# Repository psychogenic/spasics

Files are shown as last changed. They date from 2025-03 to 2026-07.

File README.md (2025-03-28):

# SpASICs
----------

Scratch repo for work, thoughts and notes about the spasics project: sending an ASIC to space!

It may be possible for [Tiny Tapeout](https://tinytapeout.com/) to include an experiment module aboard a [pocketQube](https://en.wikipedia.org/wiki/PocketQube) class satellite, so am collecting preliminary work on this here, in the hopes of getting ideas and feedback.

## Basic Requirements

Details on the objectives and requirements are all in the PRD, [SpASICs: ASIC Modular satellite experimentation board requirements](doc/SpASICsRequirements.md).  This is also available as [a PDF](doc/spasics.pdf).

## TODO

In addition to feedback on the PRD itself, the following require further work, feedback and ideas:

   * A means to safely run arbitrary, user-submitted, experiments.  Short version is we can't hang, we can't die, no matter what.  The proposed/sample implementation is [experiment_runner.py](python/experiment_runner.py) 
   
   * A complete API for commands and responses from the base system to our module.  Details on that are in [Experiment Module API](doc/ExperimentModuleAPI.md).
   
   * A means to safely update the system (ideally this would go all the way to the uPython firmware itself but, owing to bw constraints, this may be restricted to everything above that layer).  I would like to see something like a 2-slot OTA system, where we have everything in two places, run from slot A, update to slot B, attempt to run from slot B and revert to slot A on failure otherwise slot B becomes primary... that sort of thing.  TBD in [Firmware Updates](doc/FirmwareUpdates.md).
   
   * A byte-efficient means of patching the system.  Some updates may only be changes to a few lines of code, what is the most effective means of transmitting this data?  Also TBD in [Firmware Updates](doc/FirmwareUpdates.md).
   
   * Resilient data stores for outgoing data queues, log data, scheduling information etc 
   
   * Implementation code for above, once defined
   
   * More TODOs

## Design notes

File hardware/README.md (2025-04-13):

# Experiment Module Hardware

A single PCB created to host both the ASIC and the platform for the Experiment Run and Data Collection Framework (an RP2040) for inclusion within the [pocketQube](https://en.wikipedia.org/wiki/PocketQube) class satellite.

In addition to the meeting requirements related to being included in the launch (e.g. a 3mm height maximum, no silk screen, etc), a primary goals were to

  * provide a seamless path to running [SDK](https://github.com/TinyTapeout/tt-micropython-firmware) and existing ASIC project code with minimal disruption; and
  
  * reuse as much prior-tested components and circuitry
  
Thus, to the maximum extent possible, parts and pinouts were preserved, while major schematic elements were reproduced from the [demoboard](https://github.com/tinytapeout/tt-demo-pcb) and [ASIC breakout](https://github.com/tinyTapeout/breakout-pcb).

## Board 

[Explore the design online using KiCanvas](https://kicanvas.org/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)

The basic schematic is

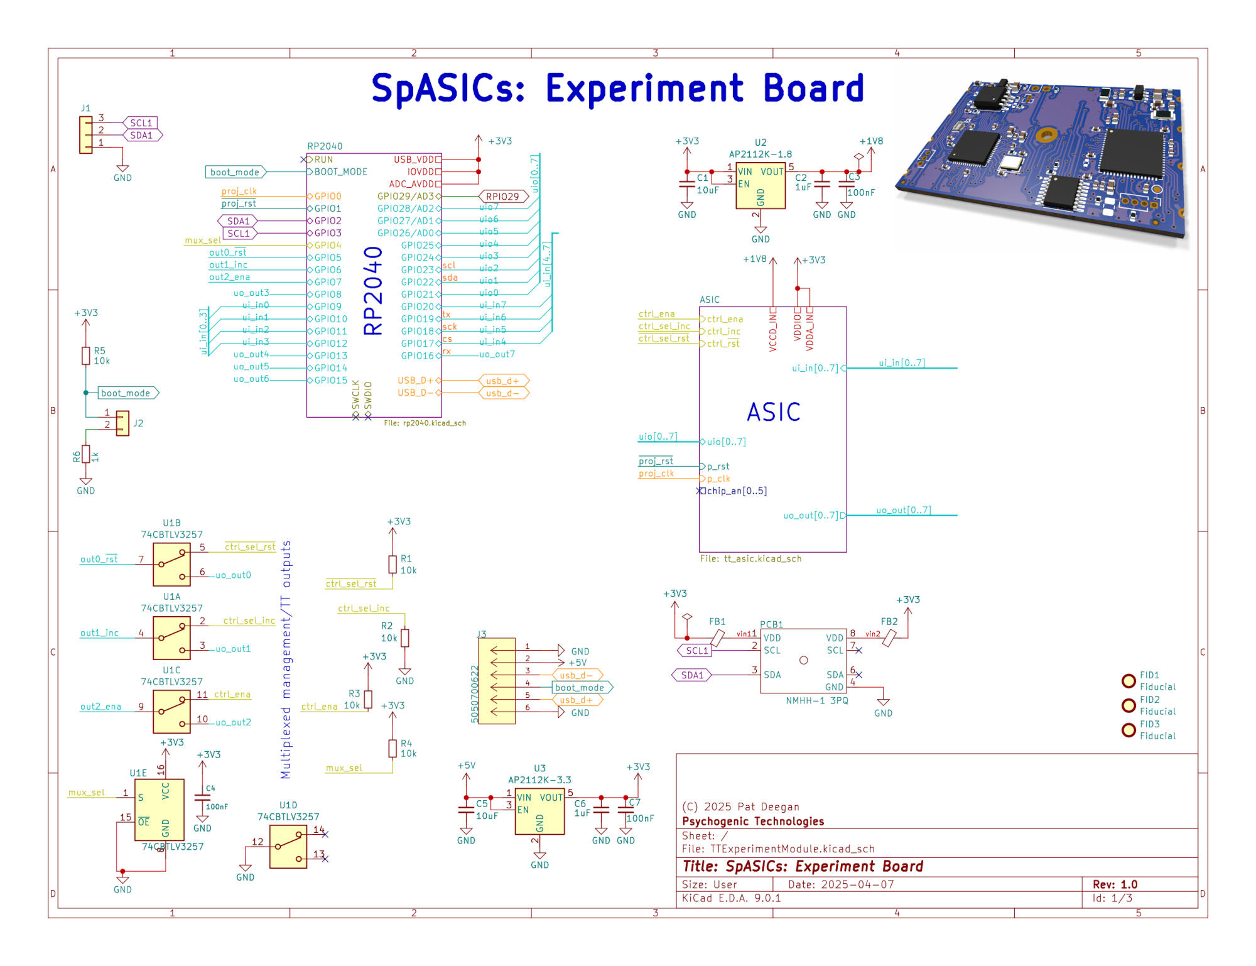
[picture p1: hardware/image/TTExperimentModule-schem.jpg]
TT Exp Board Schematic


and you can consult the entire schematic in [the PDF](image/TTExperimentModule.pdf).

The PCB is 45x30mm and is mainly concerned with routing I/O around the big hole in the middle of the board.

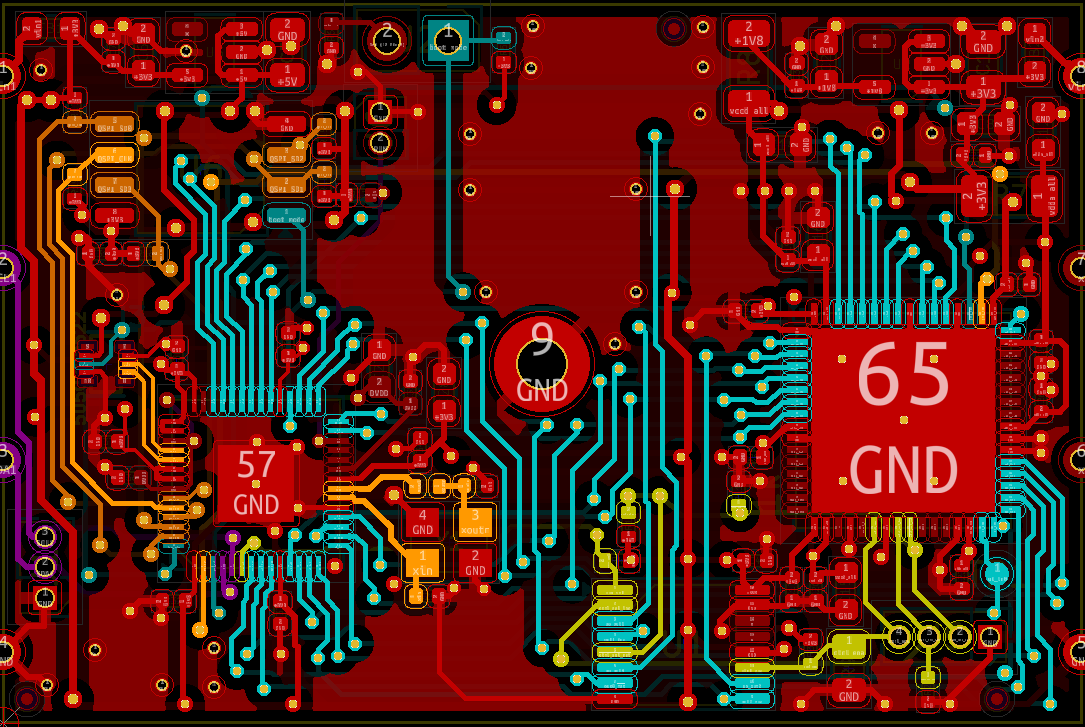
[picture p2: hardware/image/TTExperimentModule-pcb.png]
TT Exp Board PCB


## Sources

The entire [KiCad](https://www.kicad.org/) project is in [TTExperimentModule](./TTExperimentModule)

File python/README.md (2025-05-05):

# SpASICs Python Driver

This micropython codebase allows:

  * responding to the satellite as an I2C slave device
  
  * running ASIC design experiments and getting results back as they proceed and once they are done

It implements an API that supports:

  * launching and aborting user experiments
  
  * fetching status information
  
  * ping and reboot

There is also a framework in place to allow easy development of experiments to run on the module.  If you're interested in that, see the next section and you can ignore the rest.
  
## Experiment Development

Write some code that will be run IN SPACE!  Can be on your own design on TT06, or someone else's.

I've now created a framework to allow you to develop and test your spASIC experiments on TT demoboards.  It's an easy way to see that it's working and doing what you hope, in a way that integrates seamlessly with the spASIC-specific system on the experiment board.

The full description is on [spasic_experiment_testing](https://github.com/psychogenic/spasic_experiment_testing), short version is to

   1. Fork that [spasic_experiment_testing repository](https://github.com/psychogenic/spasic_experiment_testing)

   2. In your clone, create a package under `spasic.experiment` using `spasic.experiment.tt_um_test` as a guide

   3. Copy all the modules over to the demoboard and run your tests using the ExperimentRunner to ensure all is well

   4. Make a pull-request to merge your experiment prior to launch

## Testing

If you want to test this entire codebase, you'll need two devices:

  * one to play the role of the spasics board; and
  
  * one to play the role of the satellite and bus master.
  
to wire them up with 3 shared lines--I2C SDA, SCL and a common ground--and to get a little deeper into the weeds to have the "spasics board" setup.

### satellite simulator

For the satellite, there is [simulator code](./i2c_client_test.py) that can be installed on any micropython device, such as a Pi Pico, as `main.py` and allows you to use the REPL to talk over I2C to the spasics board. 

This code knows how to craft messages and interpret what comes back and has useful methods, e.g.

  * `sim.run_experiment_now(EXPID)` to launch an experiment
  
  * `sim.abort()` to stop an experiment in progress 
  
  * `sim.status()` to read status (experiment running, current results value, etc)
  
  * `sim.ping()` simple check that spasics is alive 
  
  * `sim.reboot()` ... you can probably guess, and
  
  * `sim.read_pending()` to fetch any pending messages on the spasics, such as results of experiments that have completed.
 
### spasics board

Getting a spasics board running is a bit more involved, as the RP2 micropython does *not* currently support I2C slave implementations.

So I had to go deep into the weeds and code up a micropython C module to get it working with our Python.

You'll therefore need a version of uPython with this module built-in.  I have the uPython branch with the C module here: [https://github.com/psychogenic/micropython/tree/rp2-i2cslave](https://github.com/psychogenic/micropython/tree/rp2-i2cslave)

Get that, checkout the rp2-i2cslave branch (`git checkout rp2-i2cslave`), and then copy:

   * all the contents of the [ttboard module directory](https://github.com/TinyTapeout/tt-micropython-firmware/tree/main/src)
   
   * all the contents of the [microcotb module directory](https://github.com/psychogenic/microcotb/tree/main/src)
   
Into `ports/rp2/modules`.  Then build, which is mostly just go into `ports/rp2` and

```
make submodules
make
```

Then you'll have a `firmware.uf2` in build-somethingsomething that you can install.

If you install this UF2, you'll have the spasics basics and you could simply copy over the [spasics API modules](https://github.com/psychogenic/spasics/tree/main/python/spasic) and the [shuttles](https://github.com/psychogenic/spasics/tree/main/python/shuttles) directory and [config.ini](https://github.com/psychogenic/spasics/blob/main/python/config.ini) [i2c_server.py](https://github.com/psychogenic/spasics/blob/main/python/i2c_server.py) and [main.py](https://github.com/psychogenic/spasics/blob/main/python/main.py), from here, into the root of the micropython filesystem.

However, if you are playing deep enough that you have to install the UF2 repeatedly, this process of copying everything over can quickly get tiresome.  

If you want, you can instead take that base UF2 and automatically have the filesystem filled with all the goodness.  To do this, create a directory that will act as the root of the FS, say `upyfs`.  Then, into that directory copy over all the above, so you have:

```
	upyfs/config.ini
	upyfs/i2c_server.py
	upyfs/main.py
	upyfs/shuttles/
	upyfs/spasic/
```

Now, install [uf2utils](https://pypi.org/project/uf2utils/) using `pip install uf2utils`.  With the `firmware.uf2` and the root directory in hand, you can now run

```
python -m uf2utils.examples.custom_pico \
   --fs_root upyfs/ --upython firmware.uf2 \
   --out /tmp/mybundled-distro.uf2
```

Installing the new `/tmp/mybundled-distro.uf2` rather than just the bare `firmware.uf2` will be a bit slower, but it will include everything that was under your `upyfs`.  Horray.
￼

For the spasics board, SDA is GPIO2 and SCL is GPIO3, by default. On TT06 demoboards, GPIO2 is the mux control reset (cRST on the header at the top) and GPIO3 is mux control increment (cINC on same header).  So, if you run this on a demoboard, you'll either want to remove the ASIC or remap the I2C pins to something better (say some bidirs, say uio1 and uio2 bidirs... main thing is that they use I2C1 on the RP2 unless you want to mess in the C module).

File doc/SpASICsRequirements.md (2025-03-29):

# SpASICs: ASIC Modular satellite experimentation board requirements      
--------------------------------------------------------------------

[Pat Deegan](https://psychogenic.com)

2025-03-26

### 1 Introduction

It may be possible for [Tiny Tapeout](https://tinytapeout.com/) to include an experiment module aboard a [pocketQube](https://en.wikipedia.org/wiki/PocketQube) class satellite and we would like to take advantage of this opportunity to put one of the ASICs produced into low earth orbit in order to run user and interact with user designs, to collect and report data from these runs back to Earth.

To attain this goal, three fundamental elements must be designed to work together:

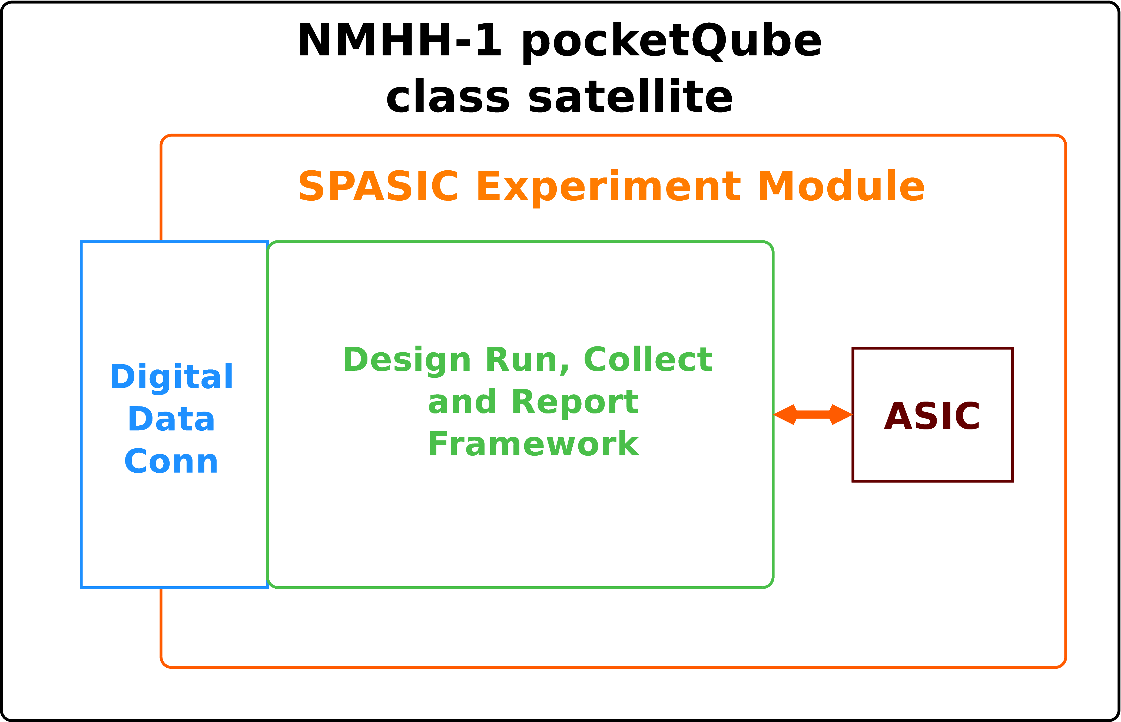
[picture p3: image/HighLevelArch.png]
High Level Architecture


1.  The experiment module: a physical PCB hosting ASIC and supporting components
    
2.  A software framework to schedule and perform runs of experiments, which will enable designs, interact with them, collect data and prepare it for reporting results; and
    
3.  The digital data connection: the means for the experiment module to communicate with and be controlled by the host satellite.

### 2 Objectives

The core objective is to get user designs operating in low earth orbit and, in doing so, acquire experience with and design tools for performing experiments in this constrained and unique environment.

The chips host a variety of designs submitted by creators and Tiny Tapeout is an educational project centred on education and community, so a collaborative model where designers can submit tests for particular projects is highly desirable. However,

because in these circumstances physical access is impossible and communications are extremely limited in both the amount of data that may be exchanged and the windows during which such exchanges are possible, the aim is to design a system that allows these user contributions while being resilient, fault-tolerant and simple.

#### 2.1 Experiment Module

The experiment module hardware is the physical PCB that may be hosted by the NMHH-1 pocketQube satellite. It’s objectives are to:

1.  Host a Tiny Tapeout ASIC and the minimal set of required supporting components for it to operate
    
2.  Meet the NMHH-1 requirements for 3PQ size pocketQube class satellite experiment modules and be suitable for inclusion in the launch
    
3.  Allow for communication between the satellite framework and the experiment run and data collection system

#### 2.2 Experiment Run and Data Collection Framework

##### 2.2.1 Experimental Run

An experimental run is the combination of:

1.  the specific design to enable on the ASIC
    
2.  any interaction required with the project, including clocking, values input through I/O and timing thereof
    
3.  data collection, including monitoring project outputs
    
4.  data processing, which condenses collected data into some form of result to be logged or returned back to base station
    
5.  reporting, i.e. providing information on the experimental run in an agreed-upon form

##### 2.2.2 Core Function

The base function of this framework is to run experiments on behalf of users. It will

1.  Maintain the set of potential design experiments
    
2.  Maintain the schedule of experimental runs
    
3.  Allocate time and processing to experimental runs according to the schedule
    
4.  Maintain records of experimental runs performed
    
5.  Collect, prepare and queue data reported by experimental runs
    
6.  Provide experimental run data to the Digital Data Communications layer on request
    
7.  Keep track of which reports are pending or have already been transmitted
    
8.  Be capable of reporting information on it’s own state, including health, information about up-time, experiment queue, global success rate

The objective is for this system to run autonomously. For example, if we suddenly could no longer communicate up to the satellite, we would still be able to receive regular reports on the set of design experiments as it was configured on last update.

##### 2.2.3 Management Function

In addition to its core function of actually performing experimental runs, the framework must allow for management functions that let us

1.  Enable or disable specific experimental runs
    
2.  Change the scheduling or weight of particular design experiments
    
3.  Set system-level parameters and limits, including system clock frequency
    
4.  Update experimental run execution code
    
5.  Update the platform firmware itself

These last two points are objectives that would be ideal to support but are subject to the extreme bandwidth constraints and difficult to implement in a manner that is guaranteed to be fault-tolerant, with item 4 potentially putting the entire platform at risk... further consideration needed here.

#### 2.3 Digital Data Communications with pocketQube

The pocketQube digital data communications protocol is a simple, 3 command, 100kHz I2C that treats the experiment module as a slave device and has only 3 commands:

1.  read
    
2.  write
    
3.  time synch

From our side, the objectives are

1.  Support handling the defined I2C messages addressed to our module and to general-call broadcasts
    
2.  Synchronize system time to satellite on reception of time synch broadcasts
    
3.  Have a clearly defined API which can be transported as payload data within the established read/write protocol
    
4.  Support all the functions of the Experiment Run and Data Collection Framework within the constraints of the limited throughput of the digital data communications protocol

### 3 Requirements

#### 3.1 Experiment Module

The experiment module PCB requirements and constraints are detailed in the “NMHH-1 3PQ size pocketQube class satellite Experiment Module” document (nmhh1\_experiments\_eng.pdf) and that document should be referred to for all details. Our module must at a minimum include

1.  a Tiny Tapeout ASIC
    
2.  a means to manage and interact with that ASIC, nominally an RP2040 MCU
    
3.  interconnects between the MCU and the ASIC
    
4.  supporting components, such as flash memory

#### 3.2 Experiment Run and Data Collection Framework

The software framework must:

1.  Be remotely updatable, at a minimum in terms of all code above the base micropython environment and data stored on the filesystem
    
2.  Prioritize responsivity and always being in a state that will react to remote commands and updates
    
3.  Allow for loading experiments in a modular fashion, without being vulnerable to faulty code within (meaning being able to recover from exceptions, crashes or hangs in user-submitted code)
    
4.  Provide a standardized mechanism for defining user-defined test units and including them within the schedule
    
5.  Provide a standardized means of reporting experimental run results
    
6.  Be able to run autonomously while supporting functions to manage scheduling, data stores and behaviour
    
7.  Be “re-entrant” in the sense that it minimizes losses to state to at most the data for a single run in progress should power interrupted at any moment
    
8.  Have a means to check and handle priority commands or start-up or at any point, in order to abort or amend work in progress

#### 3.3 Digital Data Communications with pocketQube

The Digital Data Comms layer must:

1.  Respond correctly to module-addressed and broadcast messages over the I2C bus
    
2.  Have priority over the experiment run and data collection framework, in order to respond in a timely manner to the satellite and allow for management regardless of experimental run behaviour
    
3.  Provide a means to safely override the assigned module address

### 4 Design Constraints

#### 4.1 Experiment Module

Refer to “NMHH-1 3PQ size pocketQube class satellite Experiment Module” document (nmhh1\_experiments\_eng.pdf) for all details. Important constraints to keep in mind include

1.  The PCB must match the prescribed footprint and may have a maximum height of 3mm (including the board itself), be single-sided, gold plated, use 60/40 tin-lead eutectic and not include silk screen
    
2.  Total weight may not exceed 50g
    
3.  Power supply is 3v3 (2.7V - 3.5V)
    
4.  Power draw is limited to 100mA bursts, with an average consumption (over 90 minutes) of at most 34mA

#### 4.2 Experiment Run and Data Collection Framework

The data collection framework’s main constraints are related to memory, namely

1.  that it be able to load itself and modular experimental runs within the limits of available RAM
    
2.  that it be able to rely on the flash memory as a store for programs and collected results

#### 4.3 Digital Data Communications with pocketQube

Constraints related to communications are:

1.  Speed: the I2C bus operates at 100kHz
    
2.  Bandwidth: read and write commands have fixed payloads and we must encapsulate both data and meta-information (commands) within

##### 4.3.1 Write command

Each write, from satellite to our module, is 8 bytes of data. This severely limits the amount of information we can transfer to the module, making things like updating code rather difficult as they would be forced into a great deal of transactions on the bus. Ignoring the case of large updates, simple commands could be structured as

COMMAND DATA\[6:0\]

allowing for 7 bytes of relevant payload for any given command, with a maximum of 256 distinct commands. This can be further broken down using subcommand bytes, e.g.

SETEXPERIMENT PARAM VALUE\[5:0\]

so we could define

SETEXPERIMENT DESIGNID LOWBYTE HIGHBYTE

or

SETEXPERIMENT WEIGHT VALUE

etc.

##### 4.3.2 Read command

On each read, the experiment module is expected to send exactly 16 bytes of data. The satellite can store up to 7 such reads (a total of 112 bytes) for transmission to base station. This implies that reads must either

*   Always return a specific type of data
    
*   Sacrifice a portion of those limited returned bytes as metadata, indicating the how to interpret bytes or
    
*   Be setup in some manner by a previous write, e.g. to request specific data on next read

### 5 Assumptions and Dependencies

Core assumptions to be confirmed or amended.

1.  Module will be powered on at least 6 hours of every 24
    
2.  Under standard operating conditions, power delivery will be uninterrupted for periods of at least 20 minutes

3.  While powered, over any period of 60 seconds there will always be at least one I2C data communication transaction addressed to the module
    
4.  Ambient/materials in physical contact with the experiment module will always be between -40 and +80 degrees Celsius
    
5.  Assuming a ground plane connected via 4x 0.5mm thermal reliefs to the large plated through hole in the centre of the PCB, in combination of mechanical fastening and electrical connectivity of the experiment module is sufficient to draw and dissipate a steady 115mW of waste heat.
    
6.  The satellite can hold and write blocks of at least 50kB of data to the experiment module (split into an appropriate number of 8 byte payload write transactions)
    
7.  Writes of larger blocks of data, as described in the previous point, will occur sequentially and over a period of continuously powered operation
    
8.  We may queue both simple write commands, sending data to the experiment module, and write+read sequences where we expect a blob of data to be written followed by a read, specifying how many read operations to perform (and hence how much data to retrieve for transmission)

### 6 Success Criteria

1.  The Experiment Module meets all the physical and electrical requirements and is installable within the pocketQube satellite
    
2.  The Experiment Module remains fully operational at any temperature between -40 and +80 degrees C, including during rapid changes in temperature
    
3.  The Experiment Run and Data Collection Framework responds appropriately to all supported commands
    
4.  The Experiment Run and Data Collection Framework remains responsive regardless of the nature and contents of  
    \- individual experiments  
    \- transmitted commands  
    \- uploaded updates
    
5.  The Experiment Run and Data Collection Framework runs experiments according to schedule and provides results for transmission back to earth

### 7 Future Iterations

TBD

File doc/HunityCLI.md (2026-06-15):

# HUNITY websocket CLI

Command line interface for configuring HUNITY experiments.

This program and module allow you to connect to the ground and flight model websocket APIs to query and configure commands for experiment modules interactively, and has TAB-completion and persistent/searchable command history (readline support).

Copyright (C) 2026 Pat Deegan, [psychogenic.com](https://psychogenic.com)
Release under the GPL v3, see the LICENSE file for details.

List of available commands from the online help:

```
HUNITY CLI — type 'help' for commands, 'exit' to quit.
> help

hunity_cli.py

Interactive command-line interface to the WebSocket experiment API.
Imports and uses hunity_api.HunityAPI.

Supported CLI commands
----------------------
  set <VAR> <VALUE>          – set a variable (exp_id, user, password, port)
  get [VAR]                  – show one or all variable values
  model <GROUND|FLIGHT>      – set the model you connect to
  connect                    – open WebSocket and login
  disconnect                 – close WebSocket connection
  command_windows [NUMDAYS]  – list command windows from now to now+NUMDAYS
  command_queue  <WINDOWID> [NUMDAYS] [START]
                             – list commands for window
  send_commands <WINDOW_ID> <CSVFILE>
                             – read CSV and send each row as a command
  send_command_single <WINDOW_ID> <DEADLINE> <HEX_COMMAND>
                             – send the single command
  delete_command <CMDID>     – delete a previously queued command
  help                       – show this help

  exit / quit                – leave the CLI
```

The required files are:

 * [hunity_api.py](../python/hunity_api.py): the module supporting the API; 
 * [hunity_cli.py](../python/hunity_cli.py): the command line interface script; and
 * optionally a `hunity_api_auth.py` to preload auth creds (see Authentication, below)

## Sample Session

```
$ python python/hunity_cli.py

HUNITY CLI — type 'help' for commands, 'exit' to quit.
>
> connect
{"clients": [{"connectionId": "0x71bc94000fa0", "username": "anonymous_56"},{"connectionId": "0x71bc94037de0", "username": "hodlemil"}]}
{"clients": [{"connectionId": "0x71bc94000fa0", "username": "spasic"},{"connectionId": "0x71bc94037de0", "username": "hodlemil"}]}
login: spasic logged in
spasic (ground)> command_windows 0.25
  ID     Start                      End                      
  -----  -------------------------  -------------------------
  45773  2026-06-15T21:50:00+00:00  2026-06-15T22:00:00+00:00
  45774  2026-06-15T22:00:00+00:00  2026-06-15T22:10:00+00:00
  45775  2026-06-15T22:10:00+00:00  2026-06-15T22:20:00+00:00
  45776  2026-06-15T22:20:00+00:00  2026-06-15T22:30:00+00:00
  45777  2026-06-15T22:30:00+00:00  2026-06-15T22:40:00+00:00
  45778  2026-06-15T22:40:00+00:00  2026-06-15T22:50:00+00:00
  45779  2026-06-15T22:50:00+00:00  2026-06-15T23:00:00+00:00
  45780  2026-06-15T23:00:00+00:00  2026-06-15T23:10:00+00:00
  45781  2026-06-15T23:10:00+00:00  2026-06-15T23:20:00+00:00
  45782  2026-06-15T23:20:00+00:00  2026-06-15T23:30:00+00:00
  45783  2026-06-15T23:30:00+00:00  2026-06-15T23:40:00+00:00
spasic (ground)>
spasic (ground)>
spasic (ground)>
spasic (ground)> command_queue 45777
0 commands returned
spasic (ground)>
spasic (ground)>
spasic (ground)> send_command_single 45777 0 0000000000000053
spasic (ground)> send_command_single 45777 -20 0x007056474e500150
spasic (ground)>
spasic (ground)>
spasic (ground)> command_queue 45777
2 commands returned
QueuedCommand(command_id=100, experiment_id='spasic', 
      command='5300000000000000', windowid=45777, sent=0, 
      timestamp=2026-06-15T22:30:00+00:00)
QueuedCommand(command_id=101, experiment_id='spasic', 
      command='5001504E47567000', windowid=45777, sent=0, 
      timestamp=2026-06-15T22:30:20+00:00)
spasic (ground)>
spasic (ground)>
spasic (ground)> send_command_single 45777 -40 0x007056474e500150
spasic (ground)> command_queue 45777
3 commands returned
QueuedCommand(command_id=100, experiment_id='spasic', 
      command='5300000000000000', windowid=45777, sent=0, 
      timestamp=2026-06-15T22:30:00+00:00)
QueuedCommand(command_id=101, experiment_id='spasic', 
      command='5001504E47567000', windowid=45777, sent=0, 
      timestamp=2026-06-15T22:30:20+00:00)
QueuedCommand(command_id=102, experiment_id='spasic', 
      command='5001504E47567000', windowid=45777, sent=0, 
      timestamp=2026-06-15T22:30:40+00:00)
spasic (ground)>
spasic (ground)>
spasic (ground)> command_delete 102
Deleted successfully
spasic (ground)>
spasic (ground)>
spasic (ground)> command_queue 45777
2 commands returned
QueuedCommand(command_id=100, experiment_id='spasic', 
      command='5300000000000000', windowid=45777, sent=0, 
      timestamp=2026-06-15T22:30:00+00:00)
QueuedCommand(command_id=101, experiment_id='spasic', 
      command='5001504E47567000', windowid=45777, sent=0, 
      timestamp=2026-06-15T22:30:20+00:00)
      
spasic (ground)>
spasic (ground)> disconnect
Close timed out - forcing shutdown
Disconnected.
> 
```

## Authentication

To access your experiment, the connection and API calls need to know the experiment id as well as auth credentials, and port to connect to.

These are available and get/set through the get/set commands:

```
>
> get
  exp_id = spasic
  user = spasic
  password = ***
  port = 8280
>
> model
Usage: model <GROUND|FLIGHT>
> model FLIGHT
Port set to 8180
>
>
> get
  exp_id = spasic
  user = spasic
  password = ***
  port = 8180
> 
```

However, if a `hunity_api_auth.py` module is available, with valid values for:

```
# API creds
User = 'myuser'
Password = 'somePassword'
ExperimentID = 'ourexperiment'
```

Then this will be pre-loaded and setup for you on program start.

## commands

The list of commands available is seen through the `help`.  Commands normally also provide online help when run with no parameters:

```

spasic (ground)> send_commands
Usage: send_commands <WINDOW_ID> <CSVFILE>

spasic (ground)> delete_command
Usage: delete_command <CMDID> [MAXID]

spasic (ground)> set
Usage: set <VAR> <VALUE>
  Variables: exp_id, user, password, port

```

spasic (ground)> send_commands
Usage: send_commands <WINDOW_ID> <CSVFILE>
spasic (ground)> delete_command
Usage: delete_command <CMDID> [MAXID]
spasic (ground)>

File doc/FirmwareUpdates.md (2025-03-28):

SpASIC updates
--------------

Would be nice to have everything perfect prior to launch, but... yeah.  So a reliable means of updating code and data is required.

The [Experiment Module API](ExperimentModuleAPI.md) specifies a *PATCH* command, but just how that might work best must be determined.

The 3 main questions at this point are:

1. How can we most efficiently transmit updates and patches?

2. How can we do this in a way that keeps the system resilient and responsive in all cases?

3. Is all this possible for the entire system (meaning down to micropython itself), or must we limit ourselves to updating only our own code and data?

### OTA

It would be nice to have a safe OTA system that somehow supports multiple *slots*, i.e. a known-stable default and an alternate where patches are applied and changes made.  With such a system:

   * we boot up using the current-default slot
   
   * updates are applied to the alternate slot
   
   * a safe (e.g. watchdog protected) attempt is made to use and verify system stability using the new code base
   
   * on success, the slot roles are switched, where alternate slot is promoted to being the default

### Patching

If changes are minor or it's otherwise more efficient, we should be sending updates as patches rather than entire files.  Determination of the most condensed and reliable means to do so are TBD.

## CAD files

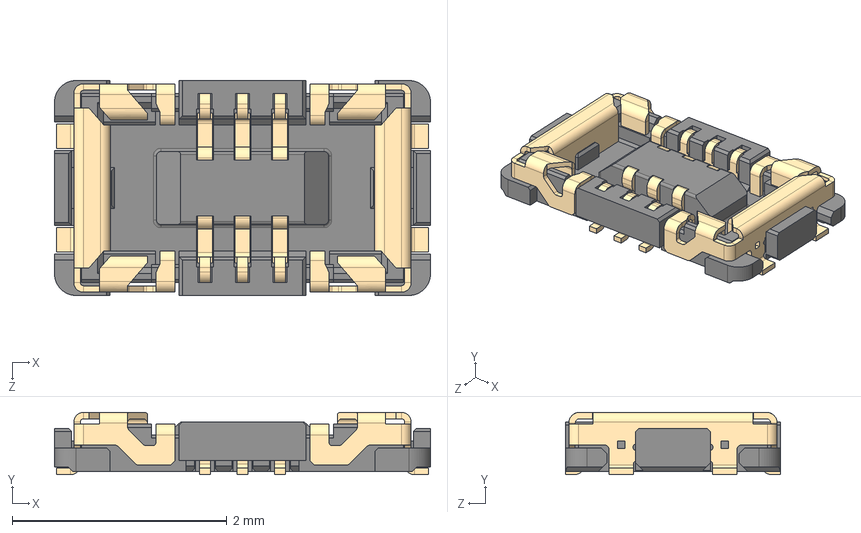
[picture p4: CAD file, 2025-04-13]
hardware/TTExperimentModule/ext/5050660622.step
3.50 x 0.58 x 2.00 mm
505066-xx22_06
B term x 2
pin x 6

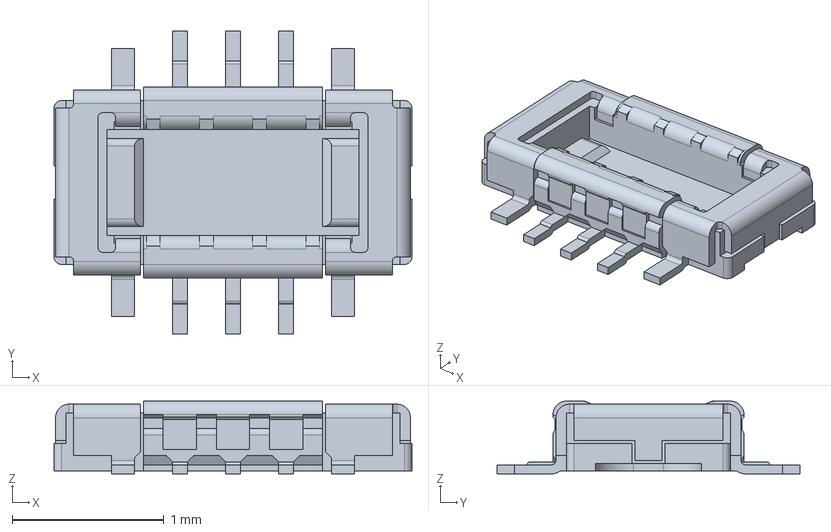
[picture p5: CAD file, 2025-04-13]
hardware/TTExperimentModule/ext/5050700622.stp
2.36 x 2.00 x 0.48 mm

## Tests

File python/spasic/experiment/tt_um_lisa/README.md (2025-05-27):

# LISA

This experiment runs a simple LISA test and sends the output down the satellite link.
The processor is fed opcodes via a PIO programmed from Python with up to 64 16-bit
opcodes PUSHed to the PIO FIFOs.  Then the processor is either single-stepped
or breakpoints are set and the core is allowed to run to the breakpoint.  Then additional
opcodes are PUSHed to the FIFO, additional breakpoints, etc.

After performing a series of basic LISA opcode tests, the code goes into a short loop
sending the string "LISA" via the UART2 peripheral.  This routes to RP2040 UART1, so
the Python code accumulates the received bytes and tests for receipt of the string.  Also
in that test loop, the LISA timer1 peripheral is enabled to generate 127ms "ticks".  The
running code waits for the timer rollover and increments a counter each time,  The total
timer1 "ticks" and receipt of "LISA" strings is recorded in two of the receive bytes.

If for any reason the processor fails to HALT at a prescribed breakpoint (i.e. some failure
occurred), then Python will record the expected address:

 - Expected PC:  response.result[1] (upper two PC bits in result[0][7:6])
 - Actual PC:    response.result[2] (upper two PC bits in result[0][5:4]).

If no error in PC breakpoints, at the end of the test, LISA will set the last result[9] byte
to 1 and copy LISA's calculation of the answer to "Life, The Universe and Everything" in
BF16 Floating point format to result[1] and result[2].  This value is calculated as one of the
opcode tests for FMUL as "sqrt(42) * sqrt(42)" and stored in the DFFRAM.  As it turns out,
the BF16 encoding for 42.0 also contains HEX 0x42, so it is reporting the "Answer" in two
formats.  :)

## Expected results

The experiment should progress as follows:

| Stage | Reported bytes |
|---|---|
| LISA Debugger detected | `0x1  0x0  0x0  0x0  0x0  0x0  0x0  0x0  0x0  0x0` |
| LISA Configuration Success | `0x2  0x0  0x0  0x0  0x0  0x0  0x0  0x0  0x0  0x0` |
| LISA Single Step Success | `0xf  0x0  0x0  0x0  0x0  0x0  0x0  0x0  0x0  0x0` |
| LISA Opcode Tests Pass | `0xf  0x0  0x0  0xff 0xff 0xff 0x7f 0x0  0x0  0x0` |
| Final result | `0xf  0x42 0x28 0xff 0xff 0xff 0x7f 0x24 0x7  0x1` |
                                     ---------                       ^    ^    ^ 
                                   BF16 42.0 (Calculated)            |    |    |
                             "Life, the Universe and Everything"     |    |  Success
                                         ^                           |    |
                                         |                           | Number of "LISA"
                               Also reports expected                 | strings received from
                               and actual PC if break                | LISA UART2 by RP2040
                               failed.  Then  "Success"              |
                               byte will be 0x00             Number of times the 
                                                             127ms timer rolled over

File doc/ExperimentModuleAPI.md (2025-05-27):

# SpASICs Experiment Module API
-------------------------------

As described in the [PRD](SpASICsRequirements.md), the interface to the module is via I2C write and read commands.

We must create an API that allows for management of and updates to the module, as well as performing its primary task of running experiments and collecting data from transmission back to Earth.

Write commands are fixed blobs 8 bytes of data.  Reads are to return 16 bytes.
Responses to commands and experimental results from the module are returned through these read commands, up to 7 of which may be queued for relaying back to us.  That's a whole 112 bytes at a time, so efficiency is something of a consideration.

## Current Implementation

The current system does its best to be mostly stateless: i.e. where it can, operations are transmitted over a single 8-byte write transaction.  This rule is broken in cases where more than 8 bytes need to be transmitted but, even in these instances, there is no required set timing or order on the commands issued.

For example, if I am writing a file, I will need to setup the destination path prior to beginning the write, but so long as power is applied, the transmission of data for the file may be interleaved with other commands like launching experiments or getting status information.

The actual implementation of the protocol mostly happens in the [i2c_server_handlers](../python/i2c_server_handlers.py) module, and is documented here.

In order to verify function during development and to assist in crafting command packets, there is also client side code, found in   [i2c_client_packets](../python/i2c_client_packets.py) and [i2c_client_test](../python/i2c_client_test.py). 

## Crafting command Packets

These client-side modules have been written such that they may be used to interact with a live board over I2C, or simply on a desktop computer, in order to inspect or export the packet contents.

To do so, it's only a matter of importing everything from `i2c_client_test` and using the `packetdump` instance.

Issuing a command will output information, as well as "packet" lines, with the hex bytes as well as any ascii values, to the right.

All multi-byte integer values used are **little-endian**.

```
>>> from i2c_client_test import *
>>>
>>>
>>> packetdump.ping()
Sending ping 1
PKT: 0x50, 0x1,0x50,0x4e,0x47, 0x0, 0x0, 0x0            P 1  P  N  G
>>>
>>> packetdump.ping()
Sending ping 2
PKT: 0x50, 0x2,0x50,0x4e,0x47, 0x0, 0x0, 0x0            P 2  P  N  G
>>>
>>> packetdump.ping(0x88)
Sending ping 136
PKT: 0x50,0x88,0x50,0x4e,0x47, 0x0, 0x0, 0x0            P 88  P  N  G
>>>
>>> packetdump.run_experiment_now(3, b'some args 123')
Requesting run of experiment 3
PKT: 0x86,0x73,0x6f,0x6d,0x65,0x20,0x61,0x72           86  s  o  m  e     a  r
PKT: 0x86,0x67,0x73,0x20,0x31,0x32,0x33, 0x0           86  g  s     1  2  3
PKT: 0x45, 0x3, 0x0, 0x0, 0x0, 0x0, 0x0, 0x0            E 3 0
>>>
>>>
>>> # collect the packets, e.g. for export
>>>
>>> packetdump.packets()
[bytearray(b'P\x01PNG\x00\x00\x00'), 
 bytearray(b'P\x02PNG\x00\x00\x00'), 
 bytearray(b'P\x88PNG\x00\x00\x00'), 
 bytearray(b'\x86some ar'), 
 bytearray(b'\x86gs 123\x00'), 
 bytearray(b'E\x03\x00\x00\x00\x00\x00\x00')]
```

I'll use this utility throughout to demonstrate packet contents.

## Available commands

All commands start with at least one command type byte, optionally followed by "sub-command" bytes or payload.  

In the following, hard-coded values will be specified in hex and variable values will just be assigned their `[LENGTH]` with 
`[A..B]` denoting a length between A and B.

### Ping

Simple method of determining life.  The ping expects one counter byte and an optional payload that will be echoed back.

The format is 

```
'P'   CNT  PAYLOAD
0x50  [1]  [0..6]
```
Sample
```
>>> packetdump.ping(0x42)
Sending ping 2
PKT: 0x50,0x42,0x50,0x4e,0x47, 0x0, 0x0, 0x0            P  B  P  N  G
```

Responds with an acknowledgement "pong" packet, containing the original counter byte and payload.

### Run Experiment (Immediate)

Running experiments is why we're up there.

Experiments will all be assigned a numeric ID.  Experiments *may* support arguments (using the next command described).

```
'E'   ID
0x45  [2]
```

Sample
```
packetdump.run_experiment_now(0x33)
Requesting run of experiment 51
PKT: 0x45,0x33, 0x0, 0x0, 0x0, 0x0, 0x0, 0x0            E  3 0

```

Responds with OK or an error message.

### Run Experiment Arguments

Because arguments may have more bytes than a single command can handle, these are cummulative and stateful.  Any length of bytes of arguments can in theory be sent over, using multiple of these commands.

Note that these must be sent prior to launching the experiment, and the state of the arguments is cleared on calling run experiment (regardless of success) and on abort.

```
'E'+'A'  ARGS
0x86     [1..7]
```

Here is a sample to launch experiment 0x44 with more arguments than can be handled with a single call.  The final packet is the launch of the experiment itself.

```
>>> packetdump.run_experiment_now(0x44, b'abc123456')
Requesting run of experiment 68
PKT: 0x86,0x61,0x62,0x63,0x31,0x32,0x33,0x34           86  a  b  c  1  2  3  4
PKT: 0x86,0x35,0x36, 0x0, 0x0, 0x0, 0x0, 0x0           86  5  6
PKT: 0x45,0x44, 0x0, 0x0, 0x0, 0x0, 0x0, 0x0            E  D 0
```

No response.

### Queue Experiment

Queue an experiment to run.  This is similar to the run now, but allows us to queue multiple experiments, whether something is running now or not.

If no experiment is currently running, the first queued experiment will be launched.  Other than the command byte itself for queueing, the process is identical to run now.

The only caveat is that this queue is non-persistent: if we power cycle or reboot, the queue goes away.

Command

```
'E'+'Q'   EXPID
0x96      [2]
```

Here's a sample queue of experiment 1 and experiment two along with some arguments.

The argument setting process is the same as for run now

```
>>> packetdump.experiment_queue(1)
Queueing experiment 1
PKT: 0x96, 0x1, 0x0, 0x0, 0x0, 0x0, 0x0, 0x0           96 1 0
>>>
>>> packetdump.experiment_queue(2, b'123abc')
Queueing experiment 2
PKT: 0x86,0x31,0x32,0x33,0x61,0x62,0x63, 0x0           86  1  2  3  a  b  c
PKT: 0x96, 0x2, 0x0, 0x0, 0x0, 0x0, 0x0, 0x0           96 2 0
>>> 
```

Responds with OK or error if no such experiment is mapped.

### Status

Requesting status will queue a response that includes information on the current (or last) experiment, its run time, its completion or if any exceptions were caught as well as (potentially partial) current results specified by the code.

It is a single byte of actual data:

```
'S'
0x53
```

Sample
```
>>> packetdump.status()
Requesting status
PKT: 0x53, 0x0, 0x0, 0x0, 0x0, 0x0, 0x0, 0x0            S
```

Responds with a status packet.

### Experiment Current Results

At the end of an experiment run, a result packet will be added to the response queue.  For experiments that run for a longer duration, or that require intermediate result reports beyond what `status` can provide, this command will prompt the system to queue a report immediately, with whatever the experiment has set in the result field at the time.

It is a single byte command

```
'E'+'I'
0x8e
```
Sample
```
>>> packetdump.experiment_current_results()
Requesting experiment current res
PKT: 0x8e, 0x0, 0x0, 0x0, 0x0, 0x0, 0x0, 0x0           8e
```

Responds with an experiment report.

### Abort

A long running (or infinite) experiment may be terminated by calling abort.

This is another single byte command.  You guessed it, it's an "A".

```
'A'
0x41
```

Sample

```
>>> packetdump.abort()
Requesting experiment abort
PKT: 0x41, 0x0, 0x0, 0x0, 0x0, 0x0, 0x0, 0x0            A
```

Responds with OK, indicating whether termination was issued.

### Time Sync

The time sync command sets the system time (ish).

It has a payload of a 4-byte integer

```
'T'   TIME
0x54  [4]
```

Sample
```
>>> packetdump.time_sync(0x12345678)
Sending time sync 305419896
PKT: 0x54,0x78,0x56,0x34,0x12, 0x0, 0x0, 0x0            T  x  V  4 12
>>> 
```

No response.

### Reboot

Reboots the system (by starving the watchdog, for a hard hard reset).

```
'R'
0x82
```

Sample

```
Sending reboot command
PKT: 0x52, 0x0, 0x0, 0x0, 0x0, 0x0, 0x0, 0x0            R 0
>>> chr(0x52)
```

Responds with OK.

### Info

Version and time information is return with 

```
'I'
0x49
```

Responds with a Info packet including version, system time and sync time.

## Filesystem Management

Updates and management of file system (checking file sizes and checksums, moving or deleting files) are now supported.

### Variable Slots
In order to support these operations, which potentially require multiple uses of long strings, a system of *variable slots* was introduced.  These will be described below but in short you can set up to 256 variables to strings of any length, giving each a unique numerical ID.

Then, in many operations, rather than passing a filename around for example, the system uses the single byte variable ID previously set up.  These will show up in the examples below.

### Make Directory

To create a directory, you set up a variable with the full path (including all parents from root) and it will create the directory if possible, including all the parents that are missing.

```
'F'   'D'   VARID
0x46  0x44  [1]
```

The command is simple but, in this sample, you'll notice the first three packets do the work of setting up a variable (id #2 in this case) and only the final packet is the command to create the directory:

```
>>> packetdump.mkdir('/path/to/targetdir')
Sending req to make dir /path/to/targetdir
PKT: 0xa9, 0x2,0x2f,0x70,0x61,0x74,0x68,0x2f           a9 2  /  p  a  t  h  /
PKT: 0x97, 0x2,0x74,0x6f,0x2f,0x74,0x61,0x72           97 2  t  o  /  t  a  r
PKT: 0x97, 0x2,0x67,0x65,0x74,0x64,0x69,0x72           97 2  g  e  t  d  i  r
PKT: 0x46,0x44, 0x2, 0x0, 0x0, 0x0, 0x0, 0x0            F  D 2
```

Responds with OK or error.

### List Directory

Get the contents, potentially over multiple queued responses, of a target directory

```
'F'   'L'   VARID
0x46  0x4c   [1]
```

Sample (in this case, variable slot 1 is used)
```
>>> packetdump.lsdir('/spasics')
Sending ls on dir /spasics
PKT: 0xa9, 0x1,0x2f,0x73,0x70,0x61,0x73,0x69           a9 1  /  s  p  a  s  i
PKT: 0x97, 0x1,0x63,0x73, 0x0, 0x0, 0x0, 0x0           97 1  c  s
PKT: 0x46,0x4c, 0x1, 0x0, 0x0, 0x0, 0x0, 0x0            F  L 1
```

Returns one or more File responses or error.

### File Upload

This isn't an actual command, but a utility in the satellite simulator and packet dumper that performs multiple operations:

   * sets up swap space and destination variables
   
   * opens (swap) file for write access
   
   * sends all the contents in write-sized chunks
   
   * closes the file that was opened for write
   
   * move the file over from swap to dest
   
   * requests file size and checksum info for dest

NOTE: In a real use case, it would be much safer to check the size and checksum on the swap file prior to proceeding to the move!

Still, this gives a good idea of the entire process and proves that it is possible to update the firmware (or at least the scripts on the FS) as we go.

```

>>> packetdump.upload_file('mytest.txt', '/path/to/dest.txt')
# set up a swap space variable (1) and destination variable (2)
PKT: 0xa9, 0x1,0x2f,0x6d,0x79,0x74,0x6d,0x70           a9 1  /  m  y  t  m  p
PKT: 0x97, 0x1,0x2e,0x74,0x78,0x74, 0x0, 0x0           97 1  .  t  x  t
PKT: 0xa9, 0x2,0x2f,0x70,0x61,0x74,0x68,0x2f           a9 2  /  p  a  t  h  /
PKT: 0x97, 0x2,0x74,0x6f,0x2f,0x64,0x65,0x73           97 2  t  o  /  d  e  s
PKT: 0x97, 0x2,0x74,0x2e,0x74,0x78,0x74, 0x0           97 2  t  .  t  x  t

# open file 1 (the swap) for write
PKT: 0x46,0x4f, 0x1,0x57, 0x0, 0x0, 0x0, 0x0            F  O 1  W

# send the data bytes in small chunks
PKT: 0x9d,0x54,0x68,0x65,0x73,0x65,0x20,0x61           9d  T  h  e  s  e     a
PKT: 0x9d,0x72,0x65,0x20,0x74,0x68,0x65,0x20           9d  r  e     t  h  e   
PKT: 0x9d,0x63,0x6f,0x6e,0x74,0x65,0x6e,0x74           9d  c  o  n  t  e  n  t
PKT: 0x9d,0x73, 0xa,0x6f,0x66,0x20,0x74,0x68           9d  s a  o  f     t  h
PKT: 0x9d,0x65,0x20,0x66,0x69,0x6c,0x65,0x2e           9d  e     f  i  l  e  .
PKT: 0x9d, 0xa, 0x0, 0x0, 0x0, 0x0, 0x0, 0x0           9d a

# close the file that was opened
PKT: 0x89, 0x0, 0x0, 0x0, 0x0, 0x0, 0x0, 0x0           89

# move the swap file (1) to destination (2)
PKT: 0x46,0x4d, 0x1, 0x2, 0x0, 0x0, 0x0, 0x0            F  M 1 2

File uploaded to /path/to/dest.txt.  Getting any pending data

Issuing request for size and checksum now
PKT: 0x46,0x53, 0x2, 0x0, 0x0, 0x0, 0x0, 0x0            F  S 2
PKT: 0x46,0x5a, 0x2, 0x0, 0x0, 0x0, 0x0, 0x0            F  Z 2

```

### Checking files

Two commands assist with checking the contents of files without having to read the entire thing:

  * size and
  
  * checksum

Both need a variable slot setup prior to use.

```
Size
'F'   'S'   VARID
0x46  0x53  [1]

Checksum
'F'   'Z'   VARID
0x46  0x5a  [1]

```

If you do these both at once, you can avoid setting up the variable slot twice.

Sample
```
>>> packetdump.check_file('/main.py')
Sending req for size/checksum for /main.py
Doing setup...
PKT: 0xa9, 0x1,0x2f,0x6d,0x61,0x69,0x6e,0x2e           a9 1  /  m  a  i  n  .
PKT: 0x97, 0x1,0x70,0x79, 0x0, 0x0, 0x0, 0x0           97 1  p  y
None
PKT: 0x46,0x53, 0x1, 0x0, 0x0, 0x0, 0x0, 0x0            F  S 1
PKT: 0x46,0x5a, 0x1, 0x0, 0x0, 0x0, 0x0, 0x0            F  Z 1
```

In this case, both a File size and File checksum response.

### File Move

Moving, or renaming, a file.  After setting up the two variable slots, it's simply

```
Size
'F'   'M'   SRCID  DESTID
0x46  0x4d   [1]    [1]
```

Sample, moving *a.txt* to *b.py*:
```
>>> packetdump.file_move('a.txt', 'b.py')
Move a.txt to b.py.  Setting up src
PKT: 0xa9, 0x1,0x61,0x2e,0x74,0x78,0x74, 0x0           a9 1  a  .  t  x  t
Setting up dest
PKT: 0xa9, 0x2,0x62,0x2e,0x70,0x79, 0x0, 0x0           a9 2  b  .  p  y
Issuing mv
PKT: 0x46,0x4d, 0x1, 0x2, 0x0, 0x0, 0x0, 0x0            F  M 1 2
>>> 
```

### File Delete

Unlinking a file is possible (use with caution of course).

```
'F'   'U'   VARID
0x46  0x55   [1]
```

Sample

```
>>> packetdump.file_delete('/path/file.txt')
Delete /path/file.txt...
PKT: 0xa9, 0x1,0x2f,0x70,0x61,0x74,0x68,0x2f           a9 1  /  p  a  t  h  /
PKT: 0x97, 0x1,0x66,0x69,0x6c,0x65,0x2e,0x74           97 1  f  i  l  e  .  t
PKT: 0x97, 0x1,0x78,0x74, 0x0, 0x0, 0x0, 0x0           97 1  x  t
# the actual delete operation on var 1
PKT: 0x46,0x55, 0x1, 0x0, 0x0, 0x0, 0x0, 0x0            F  U 1
>>> 
```

## File open

Files may be opened for read or writes.  For the open, you need to setup a variable slot and then call the right open command.  While it's open, you can issue multiple read/writes as appropriate.

```
'F'   'O'    VARID  'R'|'W'
0x46  0x4f   [1]      [1] (either 0x52 or 0x57) 
```

Sample, sending b'W' for a write, to a previously setup variable in slot 3
```
# open file using var 3 for write
PKT: 0x46,0x4f, 0x3,0x57, 0x0, 0x0, 0x0, 0x0            F  O 3  W
```

## Write to Open File

Once a file has been opened, writing to it can be done in 7-byte chunks with:

```
'F'+'W'  CONTENTS
0x9D      [1..7]

```

Sample
```
# open file from slot 1 for write
PKT: 0x46,0x4f, 0x1,0x57, 0x0, 0x0, 0x0, 0x0            F  O 1  W

# send the data bytes in small chunks
PKT: 0x9d,0x54,0x68,0x65,0x73,0x65,0x20,0x61           9d  T  h  e  s  e     a
PKT: 0x9d,0x72,0x65,0x20,0x74,0x68,0x65,0x20           9d  r  e     t  h  e   
PKT: 0x9d,0x63,0x6f,0x6e,0x74,0x65,0x6e,0x74           9d  c  o  n  t  e  n  t
PKT: 0x9d,0x73, 0xa,0x6f,0x66,0x20,0x74,0x68           9d  s a  o  f     t  h
PKT: 0x9d,0x65,0x20,0x66,0x69,0x6c,0x65,0x2e           9d  e     f  i  l  e  .
PKT: 0x9d, 0xa, 0x0, 0x0, 0x0, 0x0, 0x0, 0x0           9d a

# close the file that was opened
PKT: 0x89, 0x0, 0x0, 0x0, 0x0, 0x0, 0x0, 0x0           89
```

## Close File

It's nice to close the files you've opened.

The command is a single byte
```
'F'+'W'
0x89
```

For a sample, see just above.

## Variable store

As demonstrated above, there are variable slots that may be used to store long strings that get used in some commands.

### Setting variables

Setting actually involves two commands, one to initialize a slot to a value, and another to append to an existing value.

```
Set/Init
'V'+'S'   VARID  CONTENTS
0xA9       [1]   [1..6]

Append
'V'+'A'   VARID  CONTENTS
0x97
```

Sample using `variable_set()` to handle both the init and all the required appends:

```
>>> packetdump.variable_set(0x8, '/some/very/long/string/path/file.py')
Set variable 8 to '/some/very/long/string/path/file.py'
PKT: 0xa9, 0x8,0x2f,0x73,0x6f,0x6d,0x65,0x2f           a9 8  /  s  o  m  e  /
PKT: 0x97, 0x8,0x76,0x65,0x72,0x79,0x2f,0x6c           97 8  v  e  r  y  /  l
PKT: 0x97, 0x8,0x6f,0x6e,0x67,0x2f,0x73,0x74           97 8  o  n  g  /  s  t
PKT: 0x97, 0x8,0x72,0x69,0x6e,0x67,0x2f,0x70           97 8  r  i  n  g  /  p
PKT: 0x97, 0x8,0x61,0x74,0x68,0x2f,0x66,0x69           97 8  a  t  h  /  f  i
PKT: 0x97, 0x8,0x6c,0x65,0x2e,0x70,0x79, 0x0           97 8  l  e  .  p  y
```

### Getting variables

Getting the contents of a variable slot is simply

```
'V'   VARID
0x56   [1]

```

E.g. 

```
>>> packetdump.variable_get(0x8)
Get variable 8
PKT: 0x56, 0x8, 0x0, 0x0, 0x0, 0x0, 0x0, 0x0            V 8
```

## Responses

The responses are all parsed and understood in [i2c_client_test](../python/i2c_client_test.py), so their format is left as an exercise to the reader, for the moment ;-)

Have fun,
Pat Deegan

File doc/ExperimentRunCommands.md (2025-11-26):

# SpASICs: Sending Commands To Experiments      
--------------------------------------------------------------------

[Pat Deegan](https://psychogenic.com)

2025-11-26: Launch Day!

## 1 Introduction

We have a whole [API](./ExperimentModuleAPI.md) to run commands, like launch experiments, query status, etc.

This system allows experiment creators to specify the particulars of launching their run and getting results.

The process is simply:

  1) load up the libreoffice [ExperimentRequests spreadsheet](./ExperimentRequests.ods)
  
  2) list commands to execute in each row
  
  3) get us your ods file, or a CSV export thereof

## 2 Spreadsheet

The spreadsheet is a simple means of setting up the sequence of commands and their timing.

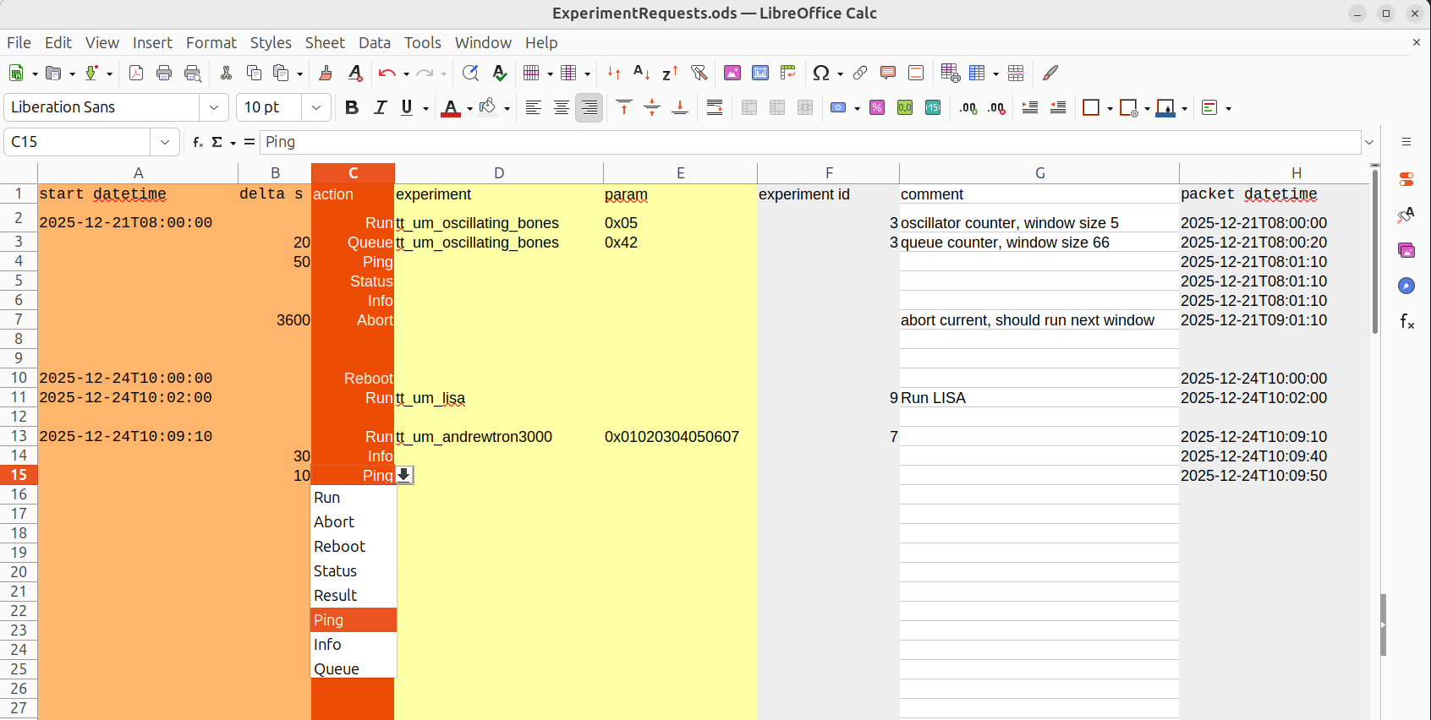
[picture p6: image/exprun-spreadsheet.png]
Spreadsheet


### Timing

The start datetime is some semi-arbitrary datetime, subject to change. Have something in there and everything else just uses the `delta` column, where you can set it to wait 60 seconds or whatever.  We only have a granularity of 10 seconds, so use 10 second increments.

### Action

The action is the command to run.  A drop down is provided for valid actions.

### Experiment

For Run or Queue commands, an experiment must be specified.  Use the name, as per the second sheet in there, e.g. *tt_um_oscillating_bones*.

When setting up the run, you may provide a sequence of bytes as a parameter.  These bytes will be sent in "big-endian" order, meaning read from left to right, i.e.

```
0x01020304
```

The comment is optional, other columns are filled for you by the sheet and should be left as-is.

## 3 Translation

Under the hood, we take this information and use the [transaction_generator](../python/transaction_generator.py) module to convert this to a format that Tibor can use to issue commands.

This winds up looking something like this

```
I2C_EXPS_EVENT_SEND_COMMAND,0,0x56,0x0000000000000586
I2C_EXPS_EVENT_SEND_COMMAND,0,0x56,0x0000000000000345
I2C_EXPS_EVENT_SEND_COMMAND,-30,0x56,0x0000000000004286
I2C_EXPS_EVENT_SEND_COMMAND,-30,0x56,0x0000000000000396
I2C_EXPS_EVENT_SEND_COMMAND,-80,0x56,0x000000474e500150
```

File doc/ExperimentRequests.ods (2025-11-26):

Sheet: commands
start datetime | delta s | action | experiment | param | experiment id | comment | packet datetime
2025-12-21T08:00:00 |  | Run | tt_um_oscillating_bones | 0x05 | 3 | oscillator counter, window size 5 | 2025-12-21T08:00:00
 | 30 | Queue | tt_um_oscillating_bones | 0x42 | 3 | queue counter, window size 66 | 2025-12-21T08:00:30
 | 50 | Ping |  |  |  |  | 2025-12-21T08:01:20
 |  | Status |  |  |  |  | 2025-12-21T08:01:20
 |  | Info |  |  |  |  | 2025-12-21T08:01:20
 | 3600 | Abort |  |  |  | abort current, should run next window | 2025-12-21T09:01:20
 | 3000 | Abort |  |  |  |  | 2025-12-21T09:51:20
 | 20 | Reboot |  |  |  |  | 2025-12-21T09:51:40
 | 200 | Run | tt_um_lisa |  | 9 | Run LISA | 2025-12-21T09:55:00
 | 1000 | Run | tt_um_andrewtron3000 | 0x01020304050607 | 7 |  | 2025-12-21T10:11:40
 | 20 | Info |  |  |  |  | 2025-12-21T10:12:00
 | 30 | Ping |  |  |  |  | 2025-12-21T10:12:30

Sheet: experiments
1 | tt_um_test
2 | tt_um_fstolzcode
3 | tt_um_oscillating_bones
4 | tt_um_qubitbytes_alive
5 | tt_um_urish_spell
6 | wokwi_universal_gates_049
7 | tt_um_andrewtron3000
8 | tt_um_MichaelBell_tinyQV
9 | tt_um_lisa
10 | tt_um_ttrpg_dice
11 | tt_um_msg_in_a_bottle
12 | tt_um_cejmu
13 | rp2_temperature
14 | tt_um_CKPope_top
15 | tt_um_PAL
16 | tt_um_dlmiles_muldiv8
17 | tt_um_dlmiles_muldiv8_sky130faha
18 | tt_um_ttrpg_SEU
128 | tt_contributors

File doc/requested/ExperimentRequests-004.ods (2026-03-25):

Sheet: commands
start datetime | delta s | action | experiment | param | experiment id | comment | packet datetime
2026-01-23T08:00:00 |  | Status |  |  |  |  | 2026-01-23T08:00:00
 | 20 | Ping |  |  |  |  | 2026-01-23T08:00:20
 | 10 | Run | tt_um_MichaelBell_tinyQV | 0x0200000459 | 8 | Tests 601 for primality, should be prime | 2026-01-23T08:00:30
 | 10 | Queue | tt_um_MichaelBell_tinyQV | 0x03 | 8 | “tQSpASIC" in first 8 bytes of result | 2026-01-23T08:00:40
 | 90 | Run | tt_um_MichaelBell_tinyQV | 0x0200000549 | 8 | Tests 713 for primality, should have factor 23 | 2026-01-23T08:02:10
 | 10 | Queue | tt_um_MichaelBell_tinyQV | 0x0200000f6a | 8 | Tests 2026 for primality, should have factor 2 | 2026-01-23T08:02:20
 | 70 | Reboot |  |  |  |  | 2026-01-23T08:03:30
 | 50 | Run | rp2_temperature | 0x11000000BA | 13 |  | 2026-01-23T08:03:10
 | 40 | Result |  |  |  |  | 2026-01-23T08:03:50
 | 10 | Run | tt_um_oscillating_bones | 0x10 | 3 |  | 2026-01-23T08:04:00
 | 360 | Reboot |  |  |  |  | 2026-01-23T08:10:00
 | 40 | Run | tt_um_ttrpg_dice | 0x22 | 10 |  | 2026-01-23T08:10:40
 | 10 | Status |  |  |  |  | 2026-01-23T08:10:50
 | 10 | Abort |  |  |  |  | 2026-01-23T08:11:00
 | 10 | Run | rp2_temperature | 0x11000000BA | 13 |  | 2026-01-23T08:11:10
 | 10 | Queue | tt_um_oscillating_bones | 0x10 | 3 |  | 2026-01-23T08:11:20
 | 1080 | Reboot |  |  |  |  | 2026-01-23T08:29:20
 | 50 | Run | rp2_temperature | 0x11000000BA | 13 |  | 2026-01-23T08:30:10
 | 10 | Queue | tt_um_oscillating_bones | 0x10 | 3 |  | 2026-01-23T08:30:20
 | 1080 | Reboot |  |  |  | F | 2026-01-23T08:48:20
 | 50 | Ping |  | 0x52425432 |  |  | 2026-01-23T08:49:10
 | 10 | Run | rp2_temperature | 0x11000000BA | 13 |  | 2026-01-23T08:49:20
 | 10 | Queue | tt_um_oscillating_bones | 0x10 | 3 |  | 2026-01-23T08:49:30
 | 1080 | Reboot |  |  |  |  | 2026-01-23T09:07:30
 | 50 | Run | rp2_temperature | 0x11000000BA | 13 |  | 2026-01-23T09:08:20
 | 10 | Queue | tt_um_oscillating_bones | 0x10 | 3 |  | 2026-01-23T09:08:30
 | 1080 | Reboot |  |  |  |  | 2026-01-23T09:26:30
 | 50 | Run | rp2_temperature | 0x11000000BA | 13 |  | 2026-01-23T09:27:20
 | 10 | Queue | tt_um_oscillating_bones | 0x10 | 3 |  | 2026-01-23T09:27:30
 | 1080 | Reboot |  |  |  |  | 2026-01-23T09:45:30
 | 50 | Run | tt_um_ttrpg_SEU |  | 18 |  | 2026-01-23T09:46:20
 | 3600 | Abort |  |  |  |  | 2026-01-23T10:46:20
 | 10 | Run | rp2_temperature | 0x11000000BA | 13 |  | 2026-01-23T10:46:30

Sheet: experiments
1 | tt_um_test
2 | tt_um_fstolzcode
3 | tt_um_oscillating_bones
4 | tt_um_qubitbytes_alive
5 | tt_um_urish_spell
6 | wokwi_universal_gates_049
7 | tt_um_andrewtron3000
8 | tt_um_MichaelBell_tinyQV
9 | tt_um_lisa
10 | tt_um_ttrpg_dice
11 | tt_um_msg_in_a_bottle
12 | tt_um_cejmu
13 | rp2_temperature
14 | tt_um_CKPope_top
15 | tt_um_PAL
16 | tt_um_dlmiles_muldiv8
17 | tt_um_dlmiles_muldiv8_sky130faha
18 | tt_um_ttrpg_SEU
128 | tt_contributors

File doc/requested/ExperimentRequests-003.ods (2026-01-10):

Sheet: commands
start datetime | delta s | action | experiment | param | experiment id |  | packet datetime
2026-01-10T08:00:00 | 10 | Ping |  | 0x5454525831 |  | Ping TTRX1 | 2026-01-10T08:00:00
 | 10 | Run | tt_um_oscillating_bones | 0x20 | 3 | Run tt_um_oscillating_bones | 2026-01-10T08:00:10
 | 0 | Queue | rp2_temperature | 0x000000000F0000 | 13 | Queue rp2_temperature | 2026-01-10T08:00:10
 | 40 | Abort |  |  |  | abort osc bones auto-launching rp temp | 2026-01-10T08:00:50
 | 10 | Queue | tt_um_fstolzcode |  | 2 | Queue tt_um_fstolzcode | 2026-01-10T08:01:00
 | 40 | Abort |  |  |  | abort rp2 temp auto-starting tt_um_fstolzcode | 2026-01-10T08:01:40
 | 240 | Abort |  |  |  | ensure tt_um_fstolzcode is done | 2026-01-10T08:05:40
 | 0 | Ping |  | 0x4c5031 |  | Ping LP1 | 2026-01-10T08:05:40
 | 10 | Run | tt_um_oscillating_bones | 0x20 | 3 | Run tt_um_oscillating_bones | 2026-01-10T08:05:50
 | 0 | Queue | rp2_temperature | 0x000000000F0000 | 13 | Queue rp2_temperature | 2026-01-10T08:05:50
 | 40 | Abort |  |  |  | abort osc bones auto-launching rp temp | 2026-01-10T08:06:30
 | 10 | Queue | tt_um_qubitbytes_alive |  | 4 | Queue tt_um_qubitbytes_alive | 2026-01-10T08:06:40
 | 40 | Abort |  |  |  | abort rp2 temp auto-starting tt_um_qubitbytes_alive | 2026-01-10T08:07:20
 | 240 | Abort |  |  |  | ensure tt_um_qubitbytes_alive is done | 2026-01-10T08:11:20
 | 0 | Ping |  | 0x4c5032 |  | Ping LP2 | 2026-01-10T08:11:20
 | 10 | Run | tt_um_oscillating_bones | 0x20 | 3 | Run tt_um_oscillating_bones | 2026-01-10T08:11:30
 | 0 | Queue | tt_contributors | 0x01 | 128 | Queue tt_contributors | 2026-01-10T08:11:30
 | 40 | Abort |  |  |  | abort osc bones auto-launching contrib loto | 2026-01-10T08:12:10
 | 10 | Queue | tt_um_urish_spell |  | 5 | Queue tt_um_urish_spell | 2026-01-10T08:12:20
 | 240 | Abort |  |  |  | ensure tt_um_urish_spell is done | 2026-01-10T08:16:20
 | 0 | Ping |  | 0x4c5033 |  | Ping LP3 | 2026-01-10T08:16:20
 | 10 | Run | tt_um_oscillating_bones | 0x20 | 3 | Run tt_um_oscillating_bones | 2026-01-10T08:16:30
 | 0 | Queue | rp2_temperature | 0x000000000F0000 | 13 | Queue rp2_temperature | 2026-01-10T08:16:30
 | 40 | Abort |  |  |  | abort osc bones auto-launching rp temp | 2026-01-10T08:17:10
 | 10 | Queue | wokwi_universal_gates_049 |  | 6 | Queue wokwi_universal_gates_049 | 2026-01-10T08:17:20
 | 40 | Abort |  |  |  | abort rp2 temp auto-starting wokwi_universal_gates_049 | 2026-01-10T08:18:00
 | 240 | Abort |  |  |  | ensure wokwi_universal_gates_049 is done | 2026-01-10T08:22:00
 | 0 | Ping |  | 0x4c5034 |  | Ping LP4 | 2026-01-10T08:22:00
 | 10 | Run | tt_um_oscillating_bones | 0x20 | 3 | Run tt_um_oscillating_bones | 2026-01-10T08:22:10
 | 0 | Queue | rp2_temperature | 0x000000000F0000 | 13 | Queue rp2_temperature | 2026-01-10T08:22:10
 | 40 | Abort |  |  |  | abort osc bones auto-launching rp temp | 2026-01-10T08:22:50
 | 10 | Queue | tt_um_andrewtron3000 |  | 7 | Queue tt_um_andrewtron3000 | 2026-01-10T08:23:00
 | 40 | Abort |  |  |  | abort rp2 temp auto-starting tt_um_andrewtron3000 | 2026-01-10T08:23:40
 | 240 | Abort |  |  |  | ensure tt_um_andrewtron3000 is done | 2026-01-10T08:27:40
 | 0 | Ping |  | 0x4c5035 |  | Ping LP5 | 2026-01-10T08:27:40
 | 10 | Run | tt_um_oscillating_bones | 0x20 | 3 | Run tt_um_oscillating_bones | 2026-01-10T08:27:50
 | 0 | Queue | tt_contributors | 0x01 | 128 | Queue tt_contributors | 2026-01-10T08:27:50
 | 50 | Abort |  |  |  | Give anything queued a chance to run before reboot | 2026-01-10T08:28:40
 | 20 | Reboot |  |  |  |  | 2026-01-10T08:29:00
 | 40 | Run | tt_um_MichaelBell_tinyQV | 0x02 | 8 | Run tt_um_MichaelBell_tinyQV | 2026-01-10T08:29:40
 | 240 | Reboot |  |  |  |  | 2026-01-10T08:33:40
 | 40 | Ping |  | 0x50545242 |  | Ping PTRB | 2026-01-10T08:34:20
 | 240 | Abort |  |  |  | ensure tt_um_MichaelBell_tinyQV is done | 2026-01-10T08:38:20
 | 0 | Ping |  | 0x4c5036 |  | Ping LP6 | 2026-01-10T08:38:20
 | 10 | Run | tt_um_oscillating_bones | 0x20 | 3 | Run tt_um_oscillating_bones | 2026-01-10T08:38:30
 | 0 | Queue | rp2_temperature | 0x000000000F0000 | 13 | Queue rp2_temperature | 2026-01-10T08:38:30
 | 50 | Abort |  |  |  | Give anything queued a chance to run before reboot | 2026-01-10T08:39:20
 | 20 | Reboot |  |  |  |  | 2026-01-10T08:39:40
 | 40 | Run | tt_um_lisa |  | 9 | Run tt_um_lisa | 2026-01-10T08:40:20
 | 240 | Reboot |  |  |  |  | 2026-01-10T08:44:20
 | 40 | Ping |  | 0x50545242 |  | Ping PTRB | 2026-01-10T08:45:00
 | 40 | Abort |  |  |  | abort rp2 temp auto-starting tt_um_lisa | 2026-01-10T08:45:40
 | 240 | Abort |  |  |  | ensure tt_um_lisa is done | 2026-01-10T08:49:40
 | 0 | Ping |  | 0x4c5037 |  | Ping LP7 | 2026-01-10T08:49:40
 | 10 | Run | tt_um_oscillating_bones | 0x20 | 3 | Run tt_um_oscillating_bones | 2026-01-10T08:49:50
 | 0 | Queue | rp2_temperature | 0x000000000F0000 | 13 | Queue rp2_temperature | 2026-01-10T08:49:50
 | 40 | Abort |  |  |  | abort osc bones auto-launching rp temp | 2026-01-10T08:50:30
 | 10 | Queue | tt_um_ttrpg_dice |  | 10 | Queue tt_um_ttrpg_dice | 2026-01-10T08:50:40
 | 40 | Abort |  |  |  | abort rp2 temp auto-starting tt_um_ttrpg_dice | 2026-01-10T08:51:20
 | 240 | Abort |  |  |  | ensure tt_um_ttrpg_dice is done | 2026-01-10T08:55:20
 | 0 | Ping |  | 0x4c5038 |  | Ping LP8 | 2026-01-10T08:55:20
 | 10 | Run | tt_um_oscillating_bones | 0x20 | 3 | Run tt_um_oscillating_bones | 2026-01-10T08:55:30
 | 0 | Queue | tt_contributors | 0x01 | 128 | Queue tt_contributors | 2026-01-10T08:55:30
 | 40 | Abort |  |  |  | abort osc bones auto-launching contrib loto | 2026-01-10T08:56:10
 | 10 | Queue | tt_um_msg_in_a_bottle |  | 11 | Queue tt_um_msg_in_a_bottle | 2026-01-10T08:56:20
 | 240 | Abort |  |  |  | ensure tt_um_msg_in_a_bottle is done | 2026-01-10T09:00:20
 | 0 | Ping |  | 0x4c5039 |  | Ping LP9 | 2026-01-10T09:00:20
 | 10 | Run | tt_um_oscillating_bones | 0x20 | 3 | Run tt_um_oscillating_bones | 2026-01-10T09:00:30
 | 0 | Queue | rp2_temperature | 0x000000000F0000 | 13 | Queue rp2_temperature | 2026-01-10T09:00:30
 | 50 | Abort |  |  |  | Give anything queued a chance to run before reboot | 2026-01-10T09:01:20
 | 20 | Reboot |  |  |  |  | 2026-01-10T09:01:40
 | 40 | Run | tt_um_cejmu |  | 12 | Run tt_um_cejmu | 2026-01-10T09:02:20
 | 40 | Abort |  |  |  | abort rp2 temp auto-starting tt_um_cejmu | 2026-01-10T09:03:00
 | 240 | Abort |  |  |  | ensure tt_um_cejmu is done | 2026-01-10T09:07:00
 | 0 | Ping |  | 0x4c503130 |  | Ping LP10 | 2026-01-10T09:07:00
 | 10 | Run | tt_um_oscillating_bones | 0x20 | 3 | Run tt_um_oscillating_bones | 2026-01-10T09:07:10
 | 0 | Queue | rp2_temperature | 0x000000000F0000 | 13 | Queue rp2_temperature | 2026-01-10T09:07:10
 | 40 | Abort |  |  |  | abort osc bones auto-launching rp temp | 2026-01-10T09:07:50
 | 10 | Queue | tt_um_CKPope_top |  | 14 | Queue tt_um_CKPope_top | 2026-01-10T09:08:00
 | 40 | Abort |  |  |  | abort rp2 temp auto-starting tt_um_CKPope_top | 2026-01-10T09:08:40
 | 240 | Abort |  |  |  | ensure tt_um_CKPope_top is done | 2026-01-10T09:12:40
 | 0 | Ping |  | 0x4c503131 |  | Ping LP11 | 2026-01-10T09:12:40
 | 10 | Run | tt_um_oscillating_bones | 0x20 | 3 | Run tt_um_oscillating_bones | 2026-01-10T09:12:50
 | 0 | Queue | tt_contributors | 0x01 | 128 | Queue tt_contributors | 2026-01-10T09:12:50
 | 40 | Abort |  |  |  | abort osc bones auto-launching contrib loto | 2026-01-10T09:13:30
 | 10 | Queue | tt_um_PAL |  | 15 | Queue tt_um_PAL | 2026-01-10T09:13:40
 | 240 | Abort |  |  |  | ensure tt_um_PAL is done | 2026-01-10T09:17:40
 | 0 | Ping |  | 0x4c503132 |  | Ping LP12 | 2026-01-10T09:17:40
 | 10 | Run | tt_um_oscillating_bones | 0x20 | 3 | Run tt_um_oscillating_bones | 2026-01-10T09:17:50
 | 0 | Queue | rp2_temperature | 0x000000000F0000 | 13 | Queue rp2_temperature | 2026-01-10T09:17:50
 | 40 | Abort |  |  |  | abort osc bones auto-launching rp temp | 2026-01-10T09:18:30
 | 10 | Queue | tt_um_dlmiles_muldiv8 |  | 16 | Queue tt_um_dlmiles_muldiv8 | 2026-01-10T09:18:40
 | 40 | Abort |  |  |  | abort rp2 temp auto-starting tt_um_dlmiles_muldiv8 | 2026-01-10T09:19:20
 | 240 | Abort |  |  |  | ensure tt_um_dlmiles_muldiv8 is done | 2026-01-10T09:23:20
 | 0 | Ping |  | 0x4c503133 |  | Ping LP13 | 2026-01-10T09:23:20
 | 10 | Run | tt_um_oscillating_bones | 0x20 | 3 | Run tt_um_oscillating_bones | 2026-01-10T09:23:30
 | 0 | Queue | rp2_temperature | 0x000000000F0000 | 13 | Queue rp2_temperature | 2026-01-10T09:23:30
 | 40 | Abort |  |  |  | abort osc bones auto-launching rp temp | 2026-01-10T09:24:10
 | 10 | Queue | tt_um_dlmiles_muldiv8_sky130faha |  | 17 | Queue tt_um_dlmiles_muldiv8_sky130faha | 2026-01-10T09:24:20
 | 40 | Abort |  |  |  | abort rp2 temp auto-starting tt_um_dlmiles_muldiv8_sky130faha | 2026-01-10T09:25:00
 | 240 | Abort |  |  |  | ensure tt_um_dlmiles_muldiv8_sky130faha is done | 2026-01-10T09:29:00
 | 0 | Ping |  | 0x4c503134 |  | Ping LP14 | 2026-01-10T09:29:00
 | 10 | Run | tt_um_oscillating_bones | 0x20 | 3 | Run tt_um_oscillating_bones | 2026-01-10T09:29:10
 | 0 | Queue | tt_contributors | 0x01 | 128 | Queue tt_contributors | 2026-01-10T09:29:10
 | 40 | Abort |  |  |  | abort osc bones auto-launching contrib loto | 2026-01-10T09:29:50
 | 10 | Queue | tt_um_ttrpg_SEU |  | 18 | Queue tt_um_ttrpg_SEU | 2026-01-10T09:30:00
 | 240 | Abort |  |  |  | ensure tt_um_ttrpg_SEU is done | 2026-01-10T09:34:00
 | 0 | Ping |  | 0x4c503135 |  | Ping LP15 | 2026-01-10T09:34:00
 | 10 | Ping |  | 0x5454525832 |  | Ping TTRX2 | 2026-01-10T09:34:10
 | 10 | Run | tt_um_oscillating_bones | 0x20 | 3 | Run tt_um_oscillating_bones | 2026-01-10T09:34:20
 | 0 | Queue | rp2_temperature | 0x000000000F0000 | 13 | Queue rp2_temperature | 2026-01-10T09:34:20
 | 40 | Abort |  |  |  | abort osc bones auto-launching rp temp | 2026-01-10T09:35:00
 | 10 | Queue | tt_um_fstolzcode |  | 2 | Queue tt_um_fstolzcode | 2026-01-10T09:35:10
 | 40 | Abort |  |  |  | abort rp2 temp auto-starting tt_um_fstolzcode | 2026-01-10T09:35:50
 | 240 | Abort |  |  |  | ensure tt_um_fstolzcode is done | 2026-01-10T09:39:50
 | 0 | Ping |  | 0x4c503136 |  | Ping LP16 | 2026-01-10T09:39:50
 | 10 | Run | tt_um_oscillating_bones | 0x20 | 3 | Run tt_um_oscillating_bones | 2026-01-10T09:40:00
 | 0 | Queue | rp2_temperature | 0x000000000F0000 | 13 | Queue rp2_temperature | 2026-01-10T09:40:00
 | 40 | Abort |  |  |  | abort osc bones auto-launching rp temp | 2026-01-10T09:40:40
 | 10 | Queue | tt_um_qubitbytes_alive |  | 4 | Queue tt_um_qubitbytes_alive | 2026-01-10T09:40:50
 | 40 | Abort |  |  |  | abort rp2 temp auto-starting tt_um_qubitbytes_alive | 2026-01-10T09:41:30
 | 240 | Abort |  |  |  | ensure tt_um_qubitbytes_alive is done | 2026-01-10T09:45:30
 | 0 | Ping |  | 0x4c503137 |  | Ping LP17 | 2026-01-10T09:45:30
 | 10 | Run | tt_um_oscillating_bones | 0x20 | 3 | Run tt_um_oscillating_bones | 2026-01-10T09:45:40
 | 0 | Queue | tt_contributors | 0x01 | 128 | Queue tt_contributors | 2026-01-10T09:45:40
 | 40 | Abort |  |  |  | abort osc bones auto-launching contrib loto | 2026-01-10T09:46:20
 | 10 | Queue | tt_um_urish_spell |  | 5 | Queue tt_um_urish_spell | 2026-01-10T09:46:30
 | 240 | Abort |  |  |  | ensure tt_um_urish_spell is done | 2026-01-10T09:50:30
 | 0 | Ping |  | 0x4c503138 |  | Ping LP18 | 2026-01-10T09:50:30
 | 10 | Run | tt_um_oscillating_bones | 0x20 | 3 | Run tt_um_oscillating_bones | 2026-01-10T09:50:40
 | 0 | Queue | rp2_temperature | 0x000000000F0000 | 13 | Queue rp2_temperature | 2026-01-10T09:50:40
 | 40 | Abort |  |  |  | abort osc bones auto-launching rp temp | 2026-01-10T09:51:20
 | 10 | Queue | wokwi_universal_gates_049 |  | 6 | Queue wokwi_universal_gates_049 | 2026-01-10T09:51:30
 | 40 | Abort |  |  |  | abort rp2 temp auto-starting wokwi_universal_gates_049 | 2026-01-10T09:52:10
 | 240 | Abort |  |  |  | ensure wokwi_universal_gates_049 is done | 2026-01-10T09:56:10
 | 0 | Ping |  | 0x4c503139 |  | Ping LP19 | 2026-01-10T09:56:10
 | 10 | Run | tt_um_oscillating_bones | 0x20 | 3 | Run tt_um_oscillating_bones | 2026-01-10T09:56:20
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

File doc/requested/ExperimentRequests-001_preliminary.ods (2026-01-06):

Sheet: commands
start datetime | delta s | action | experiment | param | experiment id | comment | packet datetime
2025-12-12T08:00:00 |  | Status |  |  |  | request status | 2025-12-12T08:00:00
 | 20 | Ping |  | 0x01545420524f58 |  | ping test 1 | 2025-12-12T08:00:20
 | 10 | Ping |  | 0x025350414345 |  | ping test 2 | 2025-12-12T08:00:30
 | 10 | Run | tt_contributors |  | 128 | run the lottery | 2025-12-12T08:00:40
 | 10 | Result |  |  |  | get lottery result | 2025-12-12T08:00:50
 | 10 | Status |  |  |  | request status | 2025-12-12T08:01:00
 | 10 | Run | tt_um_oscillating_bones | 0x10 | 3 | run oscillator | 2025-12-12T08:01:10
 | 10 | Queue | tt_contributors |  | 128 | queue lottery 2 | 2025-12-12T08:01:20
 | 10 | Result |  |  |  | check current results | 2025-12-12T08:01:30
 | 20 | Status |  |  |  | status | 2025-12-12T08:01:50
 | 20 | Info |  |  |  | info | 2025-12-12T08:02:10
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

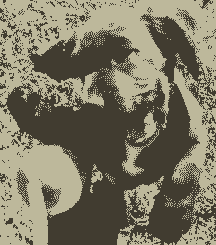
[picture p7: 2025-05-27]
python/spasic/experiment/tt_um_qubitbytes_alive/important.png

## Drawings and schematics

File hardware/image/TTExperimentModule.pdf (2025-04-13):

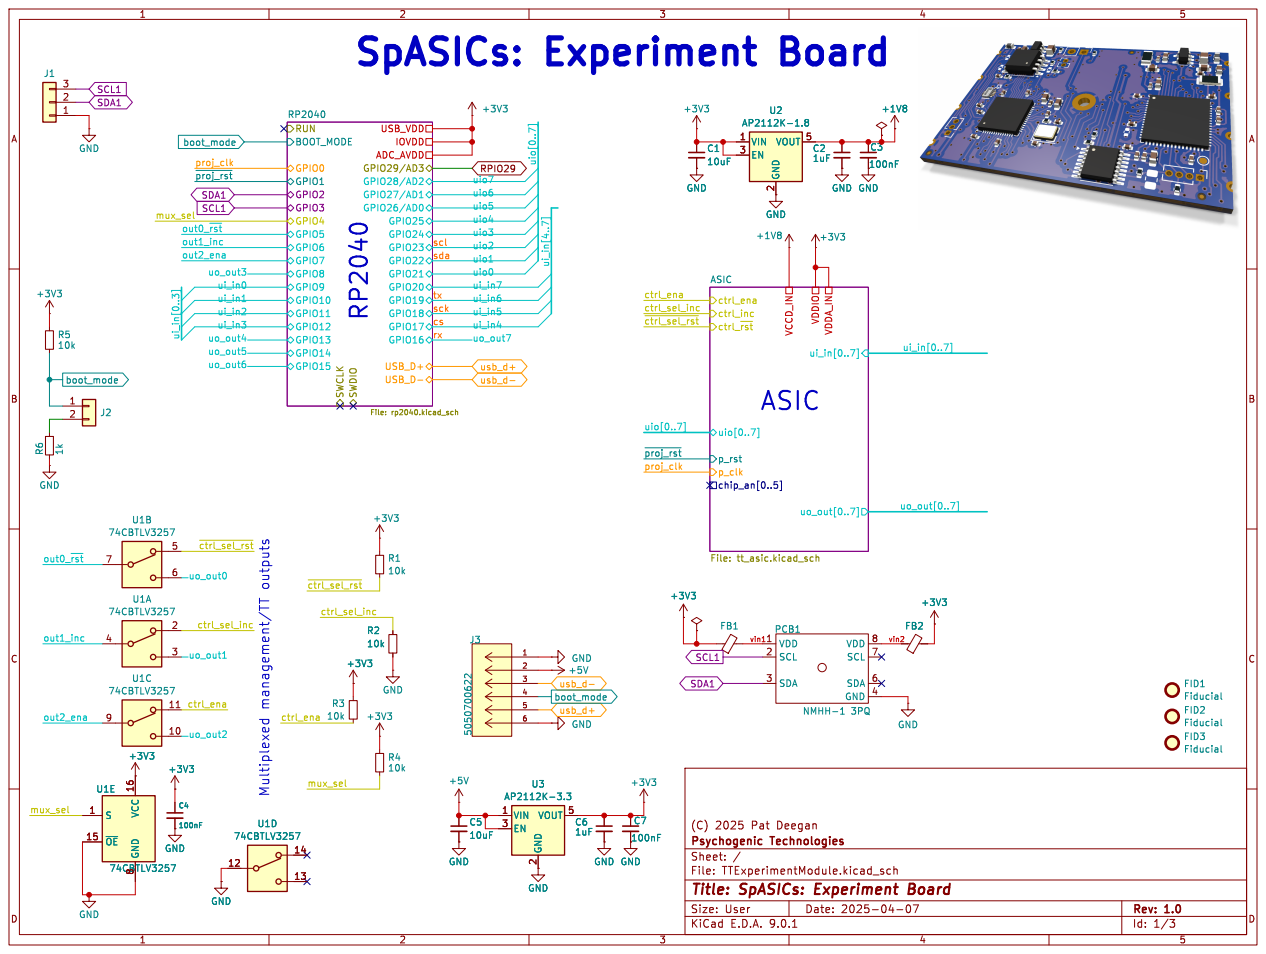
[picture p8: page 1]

2 VOUT 5 U3 AP2112K-3.3 VDD 1 SCL 2 SDA 3 VDD 8 SCL 7 SDA 6 GND 4 PCB1 NMHH-1 3PQ

Id: 1/3 Title: SpASICs: Experiment Board

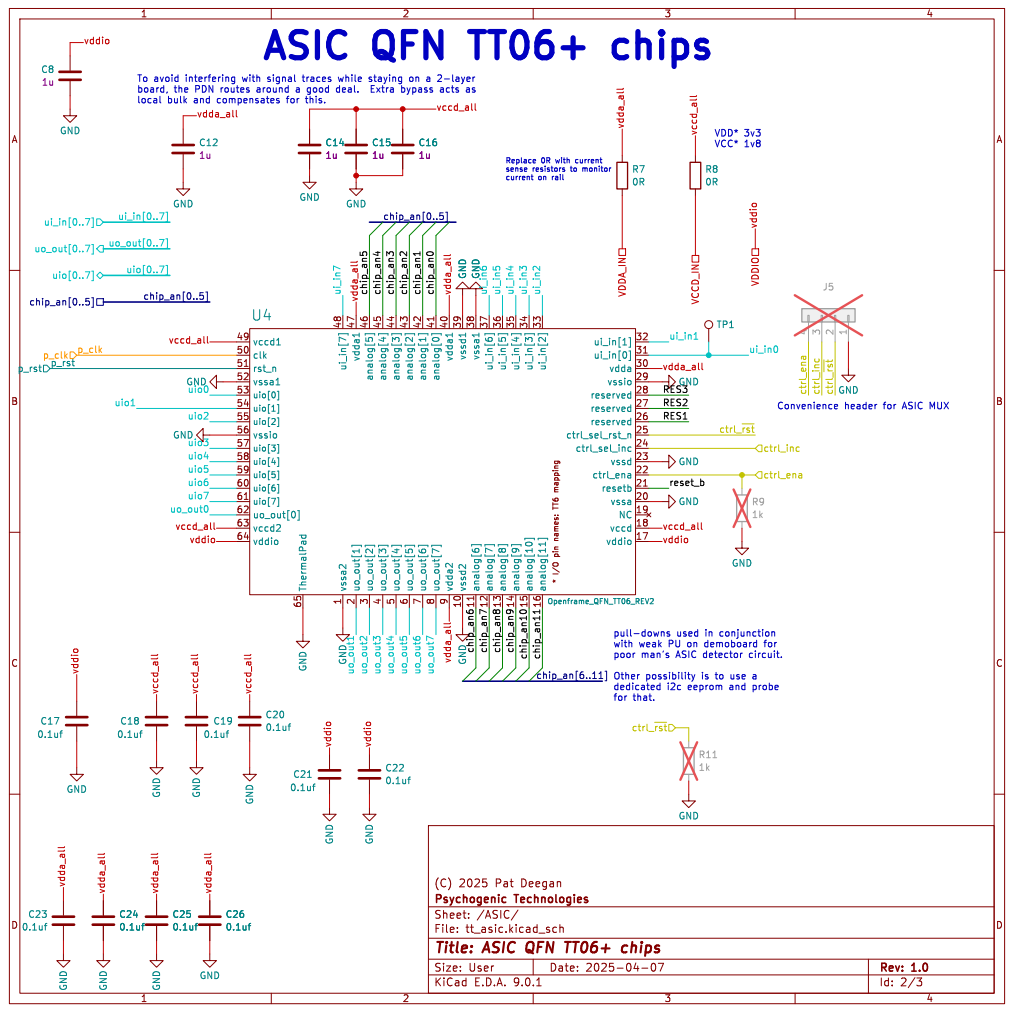
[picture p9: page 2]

for that. ASIC QFN TT06+ chips

* I/O pin names: TT6 mapping ThermalPad 65 vssa2

9 vssd2 10 analog[6] 11 analog[7] 12 analog[8] 13 analog[9] 14 analog[10] 15 analog[11] 16

Id: 2/3 Title: ASIC QFN TT06+ chips

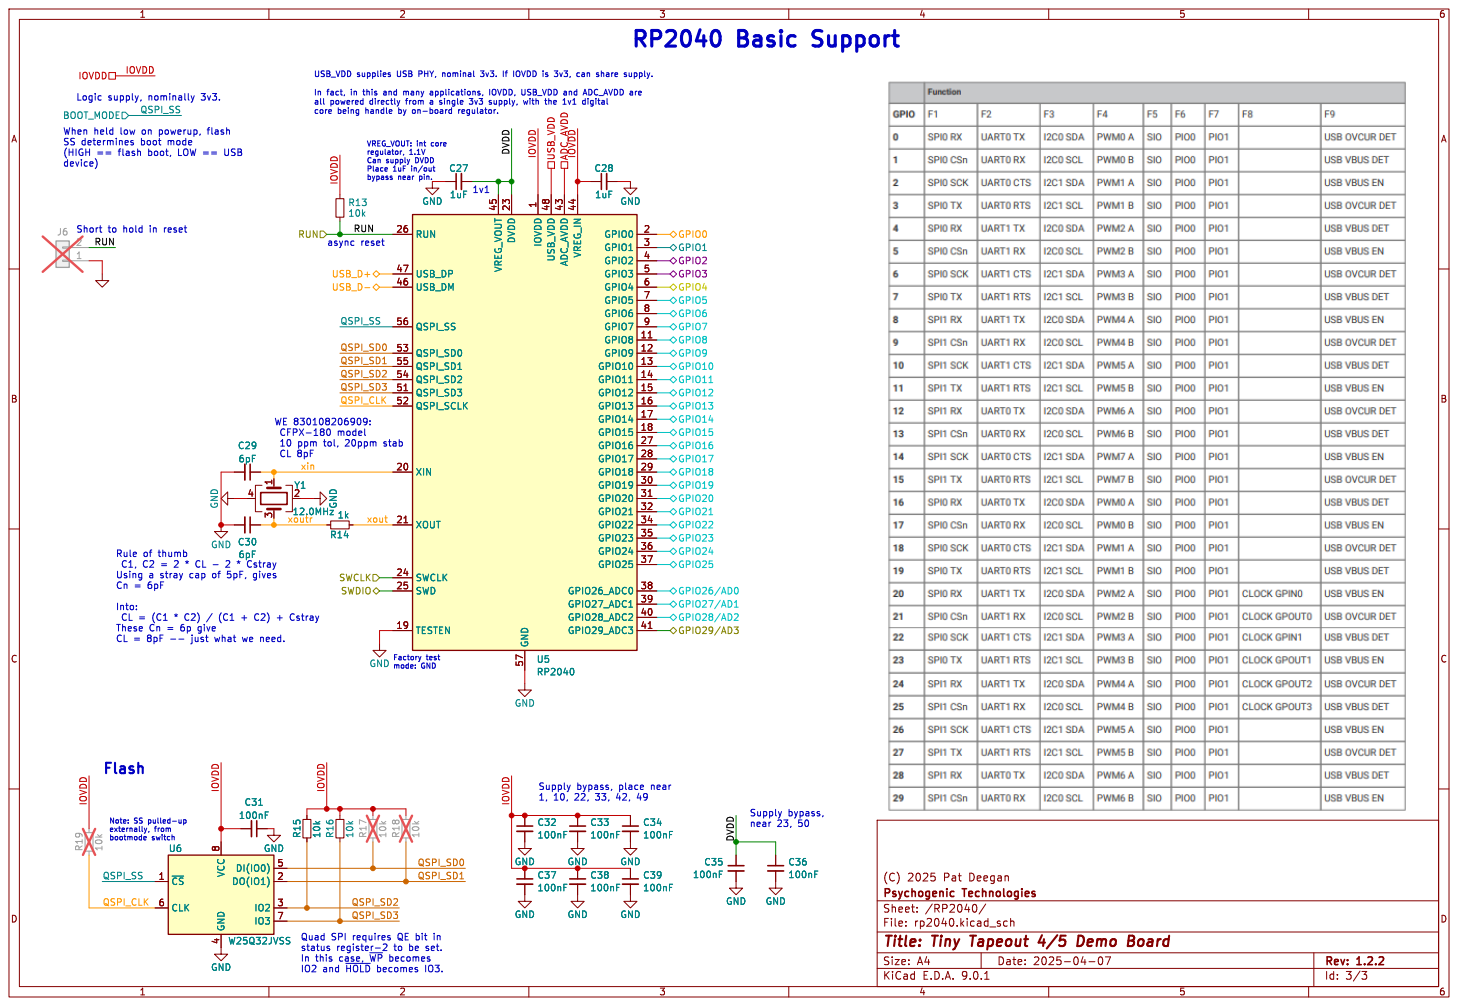
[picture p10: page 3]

(HIGH == flash boot, LOW == USB
device)

Using a stray cap of 5pF, gives Cn = 6pF

Supply bypass, near 23, 50 Flash

Note: SS pulled-up

In this case, ~{WP}becomes
IO2 and ~{HOLD}becomes IO3.

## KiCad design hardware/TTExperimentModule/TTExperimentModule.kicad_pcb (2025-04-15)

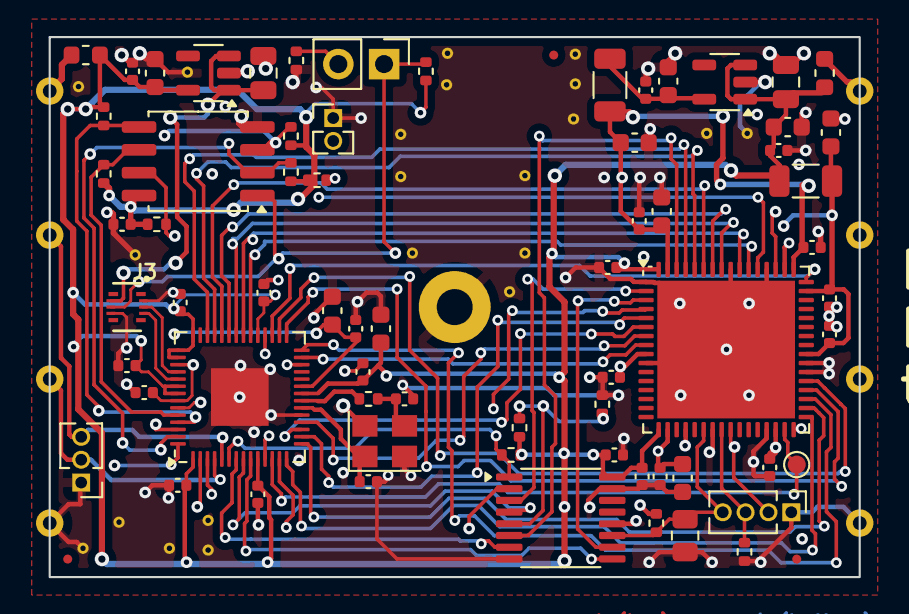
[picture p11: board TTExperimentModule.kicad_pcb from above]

Board: 4 copper layers, 45.0 x 30.0 mm, 92 parts (0 on the bottom side), 57 nets.

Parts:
C1, C5: 10uF; C_0805_2012Metric
C2, C6, C27, C28: 1uF; C_0603_1608Metric
C3, C4, C7, C31, C32, C33, C34, C35, C36, C37, C38, C39: 100nF; C_0402_1005Metric
C8, C12, C14, C15, C16: C_1u_0603_50V; C_0603_1608Metric
C17, C18, C19, C20, C21, C22, C23, C24, C25, C26: 0.1uf; C_0402_1005Metric
C29, C30: 6pF; C_0402_1005Metric
FB1, FB2: FerriteBead_Small; L_0603_1608Metric
FID1, FID2, FID3: Fiducial; Fiducial_0.5mm_Mask1mm
J1: Conn_01x03; PinHeader_1x03_P1.27mm_Vertical
J2: Conn_01x02; PinHeader_1x02_P2.54mm_Vertical
J3: 5050700622; CONN_505070-0622_MOL
J5: Conn_01x04; PinHeader_1x04_P1.27mm_Vertical
J6: Conn_01x02; PinHeader_1x02_P1.27mm_Vertical
PCB1: NMHH-1 3PQ; pocketqube_experiment
R1, R2, R3, R4, R5, R13, R15, R16, R17, R18, R19: 10k; R_0402_1005Metric
R6, R11, R14: 1k; R_0402_1005Metric
R7, R8: 0R; R_1206_3216Metric
R9: 1k; R_0805_2012Metric
STITCH1, STITCH1#2, STITCH1#3, STITCH1#4, STITCH1#5, STITCH1#6, STITCH1#7, STITCH1#8, STITCH1#9, STITCH1#10, STITCH1#11, STITCH1#12, STITCH1#13, STITCH1#14, STITCH1#15, STITCH1#16, STITCH1#17, STITCH1#18, STITCH1#19, STITCH1#20, STITCH1#21: StitchingVia-0.3mm
TP1: TestPoint; TestPoint_Pad_D1.0mm
U1: 74CBTLV3257; TSSOP-16_4.4x5mm_P0.65mm
U2: AP2112K-1.8; SOT-23-5
U3: AP2112K-3.3; SOT-23-5
U4: Openframe_QFN_TT06_REV2; QFN-64-1EP_9x9mm_P0.5mm_EP7.65x7.65mm
U5: RP2040; QFN-56-1EP_7x7mm_P0.4mm_EP3.2x3.2mm
U6: W25Q32JVSS; SOIC-8_5.3x5.3mm_P1.27mm
Y1: 12.0MHz; Crystal_SMD_3225-4Pin_3.2x2.5mm

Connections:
+1V8: C2.1, C3.1, R8.2, U2.5 (VOUT)
+3V3: C1.1, C4.1, C6.1, C7.1, C8.1, C17.2, C21.2, C22.2, C28.1, C31.2, C32.1, C33.1, C34.1, C37.1, C38.1, C39.1, FB1.1, FB2.2, R1.1, R3.2, R4.1, R5.1, R7.2, R13.1, R15.1, R16.1, R17.1, R18.1, R19.1, U1.16 (VCC), U2.1 (VIN), U2.3 (EN), U3.5 (VOUT), U4.17 (vddio), U4.64 (vddio), U5.1 (IOVDD), U5.10 (IOVDD), U5.22 (IOVDD), U5.33 (IOVDD), U5.42 (IOVDD), U5.43 (ADC_AVDD), U5.44 (VREG_IN), U5.48 (USB_VDD), U5.49 (IOVDD), U6.8 (VCC)
+5V: C5.1, J3.2, U3.1 (VIN), U3.3 (EN)
/ASIC/vccd_all: C14.1, C15.1, C16.1, C18.2, C19.1, C20.2, R8.1, U4.18 (vccd), U4.49 (vccd1), U4.63 (vccd2)
/ASIC/vdda_all: C12.1, C23.1, C24.1, C25.1, C26.2, R7.1, U4.9 (vdda2), U4.30 (vdda), U4.40 (vdda1), U4.47 (vdda1)
/RP2040/DVDD: C27.2, C35.1, C36.1, U5.23 (DVDD), U5.45 (VREG_VOUT), U5.50 (DVDD)
/RP2040/QSPI_CLK: R19.2, U5.52 (QSPI_SCLK), U6.6 (CLK)
/RP2040/QSPI_SD0: R17.2, U5.53 (QSPI_SD0), U6.5 (DI(IO0))
/RP2040/QSPI_SD1: R18.2, U5.55 (QSPI_SD1), U6.2 (DO(IO1))
/RP2040/QSPI_SD2: R15.2, U5.54 (QSPI_SD2), U6.3 (IO2)
/RP2040/QSPI_SD3: R16.2, U5.51 (QSPI_SD3), U6.7 (IO3)
/RP2040/RUN: J6.2, R13.2, U5.26 (RUN)
/RP2040/xin: C29.1, U5.20 (XIN), Y1.1
/RP2040/xout: R14.2, U5.21 (XOUT)
/RP2040/xoutr: C30.1, R14.1, Y1.3
/ctrl_ena: J5.4, R3.1, R9.1, U1.11, U4.22 (ctrl_ena)
/ctrl_sel_inc: J5.3, R2.1, U1.2, U4.24 (ctrl_sel_inc)
/mux_sel: R4.2, U1.1 (S), U5.6 (GPIO4)
/out0_~rst: U1.7, U5.7 (GPIO5)
/out1_inc: U1.4, U5.8 (GPIO6)
/out2_ena: U1.9, U5.9 (GPIO7)
/proj_clk: U4.50 (clk), U5.2 (GPIO0)
/ui_in0: TP1.1, U4.31 (ui_in[0]), U5.12 (GPIO9)
/ui_in1: U4.32 (ui_in[1]), U5.13 (GPIO10)
/ui_in2: U4.33 (ui_in[2]), U5.14 (GPIO11)
/ui_in3: U4.34 (ui_in[3]), U5.15 (GPIO12)
/ui_in4: U4.35 (ui_in[4]), U5.28 (GPIO17)
/ui_in5: U4.36 (ui_in[5]), U5.29 (GPIO18)
/ui_in6: U4.37 (ui_in[6]), U5.30 (GPIO19)
/ui_in7: U4.48 (ui_in[7]), U5.31 (GPIO20)
/uio0: U4.53 (uio[0]), U5.32 (GPIO21)
/uio1: U4.54 (uio[1]), U5.34 (GPIO22)
/uio2: U4.55 (uio[2]), U5.35 (GPIO23)
/uio3: U4.57 (uio[3]), U5.36 (GPIO24)
/uio4: U4.58 (uio[4]), U5.37 (GPIO25)
/uio5: U4.59 (uio[5]), U5.38 (GPIO26_ADC0)
/uio6: U4.60 (uio[6]), U5.39 (GPIO27_ADC1)
/uio7: U4.61 (uio[7]), U5.40 (GPIO28_ADC2)
/uo_out0: U1.6, U4.62 (uo_out[0])
/uo_out1: U1.3, U4.2 (uo_out[1])
/uo_out2: U1.10, U4.3 (uo_out[2])
/uo_out3: U4.4 (uo_out[3]), U5.11 (GPIO8)
/uo_out4: U4.5 (uo_out[4]), U5.16 (GPIO13)
/uo_out5: U4.6 (uo_out[5]), U5.17 (GPIO14)
/uo_out6: U4.7 (uo_out[6]), U5.18 (GPIO15)
/uo_out7: U4.8 (uo_out[7]), U5.27 (GPIO16)
/vin1: FB1.2, PCB1.1 (VDD)
/vin2: FB2.1, PCB1.8 (VDD)
/~ctrl_sel_rst: J5.2, R1.2, R11.1, U1.5, U4.25 (ctrl_sel_rst_n)
/~proj_rst: U4.51 (rst_n), U5.3 (GPIO1)
GND: C1.2, C2.2, C3.2, C4.2, C5.2, C6.2, C7.2, C8.2, C12.2, C14.2, C15.2, C16.2, C17.1, C18.1, C19.2, C20.1, C21.1, C22.1, C23.2, C24.2, C25.2, C26.1, C27.1, C28.2, C29.2, C30.2, C31.1, C32.2, C33.2, C34.2, C35.2, C36.2, C37.2, C38.2, C39.2, J1.1, J3.1, J3.6, J5.1, J6.1, PCB1.4 (GND), PCB1.5 (GND), PCB1.9 (GND), R2.2, R6.2, R9.2, R11.2, STITCH1.1, STITCH1#2.1, STITCH1#3.1, STITCH1#4.1, STITCH1#5.1, STITCH1#6.1, STITCH1#7.1, STITCH1#8.1, STITCH1#9.1, STITCH1#10.1, STITCH1#11.1, STITCH1#12.1, STITCH1#13.1, STITCH1#14.1, STITCH1#15.1, STITCH1#16.1, STITCH1#17.1, STITCH1#18.1, STITCH1#19.1, STITCH1#20.1, STITCH1#21.1, U1.8 (GND), U1.12, U1.15 (~OE), U2.2 (GND), U3.2 (GND), U4.1 (vssa2), U4.10 (vssd2), U4.20 (vssa), U4.23 (vssd), U4.29 (vssio), U4.38 (vssa1), U4.39 (vssd1), U4.52 (vssa1), U4.56 (vssio), U4.65 (ThermalPad), U5.19 (TESTEN), U5.57 (GND), U6.4 (GND), Y1.2, Y1.4
unnamed: J2.2, R6.1
SCL1: J1.3, PCB1.2 (SCL), U5.5 (GPIO3)
SDA1: J1.2, PCB1.3 (SDA), U5.4 (GPIO2)
boot_mode: J2.1, J3.4, R5.2, U5.56 (QSPI_SS), U6.1 (~CS)
usb_d+: J3.5, U5.47 (USB_DP)
usb_d-: J3.3, U5.46 (USB_DM)

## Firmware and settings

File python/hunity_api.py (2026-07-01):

#!/usr/bin/env python3

"""
hunity_api.py

Copyright (C) 2026 Pat Deegan, https://psychogenic.com

WebSocket client for the HUNITY experiment data/command API.
Requires: websockets (pip install websockets)

    async with HunityAPI() as api:
        await api.login("spasic", "pass")
        
        data = await api.getEXPData("spasic", 
                         dt.datetime.now(dt.timezone.utc) - timedelta(hours=12),
                         dt.datetime.now(dt.timezone.utc))
        print(data)
        

"""

SocketDomain="gnd.bme.hu"
PortGroundModel=8280
PortFlightModel=8180

import time
import ssl
import json
import asyncio
from datetime import datetime, timezone, timedelta
import datetime as dt
from dataclasses import dataclass
from typing import Union
import hashlib

import websockets

import logging
OutputVerbose = False
logLevel = logging.WARN
logging.basicConfig(
    format="%(asctime)s %(message)s",
    level=logLevel,
)
HunityAPI_User = 'spasic'
HunityAPI_ExpID = 'spasic'
HunityAPI_Password = None
try:
    import hunity_api_auth as hauth
    HunityAPI_User = hauth.User 
    HunityAPI_Password = hauth.Password
    HunityAPI_ExpName = hauth.ExperimentID
except:
    print("No hunity_api_auth found -- will request manual entry")
    


# ---------------------------------------------------------------------------
# Data types returned by the API
# ---------------------------------------------------------------------------
class ModuleCommand:
    def __init__(self):
        pass 
class CommandInterpreter:
    def __init__(self):
        pass 
    
    def process(self, raw_command:str) -> ModuleCommand:
        print("TODO:Override CommandInterpreter to provide implementation")


@dataclass
class CommandWindow:
    id: int
    start: datetime
    end: datetime

    def __repr__(self) -> str:
        return (
            f"CommandWindow(id={self.id}, "
            f"start={self.start.isoformat()}, "
            f"end={self.end.isoformat()})"
        )


@dataclass
class QueuedCommand:
    command_id: int
    timestamp: datetime
    experiment_id: str
    command: str
    windowid: int
    sent: int

    def __repr__(self) -> str:
        return (
            f"QueuedCommand(command_id={self.command_id}, "
            f"command={self.command!r}, "
            f"timestamp={self.timestamp.isoformat()}, "
            f"experiment_id={self.experiment_id!r}, "
            f"windowid={self.windowid}, "
            f"sent={self.sent}) "
        )

@dataclass 
class ExperimentData:
    timestamp: datetime 
    raw_data: str
    
    def __repr__(self) -> str:
        return (
            f"ExperimentData(timestamp={self.timestamp.isoformat()}, "
            f"data={self.raw_data})"
        )

# ---------------------------------------------------------------------------
# Main client class
# ---------------------------------------------------------------------------

class HunityAPI:
    """
    Async HunityAPI client for the experiment command/data API.

    Usage (typical async context)::

        client = HunityAPI()
        await client.open()
        await client.login("spasic", "pass")
        data = await client.getEXPData("spasic", start_dt, end_dt)
        await client.close()

    Or use as an async context manager::

        async with HunityAPI() as client:
            await client.login("spasic", "pass")
            ...
    """


    def __init__(self, port: int = PortGroundModel, 
                    domain: str = SocketDomain, ssl_context=None) -> None:
        self._domain = domain
        self._port = port
        self._uri = f"wss://{domain}:{port}/service"
        self._ws = None  # websockets connection handle
        if ssl_context is None:
            ssl_context = ssl.SSLContext(ssl.PROTOCOL_TLS_CLIENT)
            ssl_context.check_hostname = False
            ssl_context.verify_mode = ssl.CERT_NONE
        self._ssl_context = ssl_context
    # ------------------------------------------------------------------
    # Context manager support
    # ------------------------------------------------------------------

    async def __aenter__(self) -> "HunityAPI":
        await self.open()
        return self

    async def __aexit__(self, exc_type, exc_val, exc_tb) -> None:
        await self.close()

    # ------------------------------------------------------------------
    # Connection management
    # ------------------------------------------------------------------

    async def open(self) -> None:
        """Open the WebSocket connection and retain the handle."""
        if self._ws is not None:
            raise RuntimeError("Connection is already open. Call close() first.")
        self._ws = await websockets.connect(self._uri, close_timeout = None,  compression=None, user_agent_header=None, ssl=self._ssl_context)

    async def close(self) -> None:
        """Close the WebSocket connection."""
        if self._ws is not None:
            await self._ws.close()
            self._ws = None

    # ------------------------------------------------------------------
    # Private: timestamp helpers
    # ------------------------------------------------------------------

    @staticmethod
    def _to_unix(ts: Union[int, datetime]) -> int:
        """
        Convert a datetime (assumed UTC if naive) to a Unix epoch int32.
        Integers are passed through unchanged.
        Raises ValueError if the result overflows int32.
        """
        if isinstance(ts, datetime):
            if ts.tzinfo is None:
                # Treat naive datetime as UTC
                epoch = int(ts.replace(tzinfo=timezone.utc).timestamp())
            else:
                epoch = int(ts.timestamp())
        elif isinstance(ts, int):
            epoch = ts
        else:
            raise TypeError(f"Expected int or datetime, got {type(ts).__name__}")

        # int32 range: −2 147 483 648 … 2 147 483 647
        if not (-(2**31) <= epoch <= 2**31 - 1):
            raise ValueError(f"Unix timestamp {epoch} overflows int32.")
        return epoch

    @staticmethod
    def _from_unix(epoch: int) -> datetime:
        """Convert a Unix epoch integer to a UTC-aware datetime object."""
        return datetime.fromtimestamp(epoch, tz=timezone.utc)

    # ------------------------------------------------------------------
    # Private: generic command sender
    # ------------------------------------------------------------------
    async def get_response(self) -> str:
        raw = await self._ws.recv()
        
        # annoyingly, the server randomly spits out the {"clients": ... } response
        # flush that
        while '"clients"' in raw:
            print(raw)
            raw = await self._ws.recv()
        
        if OutputVerbose:
            print(f"RESPONSE: {raw}")
        return raw 
        
    async def _send_command(self, command: str, *params) -> dict:
        """
        Format and send a command string over the WebSocket.

        The wire format is:   command(param1, param2, ...)
        Parameters are converted to strings via str(); strings are NOT
        quoted in the wire format (the server handles its own parsing).

        Returns a parsed JSON object (dict or list).
        Raises:
            RuntimeError  – if the connection is not open.
            websockets.exceptions.WebSocketException – on transport errors.
            json.JSONDecodeError – if the response is not valid JSON.
        """
        if self._ws is None:
            raise RuntimeError("WebSocket is not open. Call open() first.")

        param_str = ",".join(str(p) for p in params)
        message = f"{command}({param_str})"

        if OutputVerbose:
            print(f"SENDING COMMAND: {message}")
        await self._ws.send(message)
        time.sleep(0.1)
        raw = await self.get_response()
        
        # they keep adding trailing ',' on lists and objects
        # clean those up so we can parse
        chrs = list(raw)
        i = len(chrs) - 1
        while i > 0:
            if chrs[i] == ',':
                chrs[i] = ' '
            elif chrs[i] in ['}', ']', '\n', '\r', ' ', '\t']:
                pass 
            else:
                break 
            i -= 1
            
        raw = ''.join(chrs)
        try:
            return json.loads(raw)
        except json.JSONDecodeError as exc:
            print(
                f"Response to '{command}' was not valid JSON: {raw!r}")
            return raw

    # ------------------------------------------------------------------
    # Public API commands
    # ------------------------------------------------------------------

    async def login(self, username: str, password: str) -> bool:
        """
        Authenticate with the server.

        Returns True on success, False otherwise.
        Note: the server returns a plain string (not JSON) for this command.
        """
        if self._ws is None:
            raise RuntimeError("WebSocket is not open. Call open() first.")

        enc_pass = hashlib.sha512(
                    password.encode("UTF-8")
                ).hexdigest()
        message = f"login({username}, {enc_pass})"
        
        login = (   #"{"
                    f'"username" : "{username}", '
                    f'"password" : "{enc_pass}"\n'
                    #"}"
                )   
        
        print(f"SENDING COMMAND: {login}")
        await self._ws.send(login)
        response: str  = await self.get_response()

        success = "spasic" in response.lower()
        if success:
            print(f"login: {response.strip()}")
            while 'logged in' not in response.lower():
                time.sleep(0.25)
                response = await self.get_response()
        else:
            print(f"login failed: {response.strip()}")
        return success

    async def getEXPData(
        self,
        experiment_id: str,
        start: Union[int, datetime] = None,
        end: Union[int, datetime] = None,
        data_wrapper: ExperimentData = None
    ) -> str:
        """
        Retrieve experiment data for the given time window.

        Parameters
        ----------
        experiment_id : str
        start : epoch int or datetime (or None, defaults to "now") – window start (UTC)
        end   : epoch int or datetime or timedelta (or None, defaults to +2 days) – window end   (UTC)

        Returns
        -------
            list of [datetime, data]
        """
        if start is None:
            start = datetime.now()
        if end is None:
            end = timedelta(days=2)
            
        if isinstance(end, timedelta):
            end = start + end
            
        t_start = self._to_unix(start)
        t_end = self._to_unix(end)

        try:
            payload = await self._send_command("getEXPData", experiment_id, t_start, t_end)
        except (json.JSONDecodeError, Exception) as exc:
            print(f"getEXPData error: {exc}")
            raise

        lines: list[list] = []
        try:
            datas: dict = payload.get("datas", {})
            for _exp_id, records in datas.items():
                for record in records:
                    dt = self._from_unix(record["unixtimestamp"])
                    if data_wrapper is not None:
                        lines.append(data_wrapper(timestamp=dt, raw_data=record['data']))
                    else:
                        lines.append([dt, record['data']])
        except Exception as e:
            print(f"Could not get 'datas' from {payload}: {e}")
        return lines

    async def getCMDWindows(
        self,
        start: Union[int, datetime] = None,
        end: Union[int, datetime] = None,
    ) -> list[CommandWindow]:
        """
        Retrieve command windows that fall within the given time range.

        Parameters
        ----------
        start : epoch int or datetime (or None, defaults to "now")
        end   : epoch int or datetime or timedelta (or None, defaults to +2 days)

        Returns
        -------
        list[CommandWindow]
        """
        
        if start is None:
            start = datetime.now()
        if end is None:
            end = timedelta(days=2)
            
        if isinstance(end, timedelta):
            end = start + end
        
        t_start = self._to_unix(start)
        t_end = self._to_unix(end)

        try:
            payload = await self._send_command("getCMDWindows", t_start, t_end)
        except (json.JSONDecodeError, Exception) as exc:
            print(f"getCMDWindows error: {exc}")
            raise

        windows: list[CommandWindow] = []
        for w in payload.get("commandwindows", []):
            cw =  CommandWindow(
                    id=w["id"],
                    start=self._from_unix(w["unixtimestampStart"]),
                    end=self._from_unix(w["unixtimestampStop"]),
                )
            windows.append(cw)
            
        
        return windows

    async def deleteCommand(
        self,
        experiment_id: str,
        command_id: int,
    ) -> int:
        """
        Delete a queued command

        Parameters
        ----------
        experiment_id   : str
        command_id   : int

        Returns
        -------
        int
            Server-assigned command ID on success.
        """
        try:
            payload = await self._send_command(
                "deletecommand",
                experiment_id,
                command_id
            )
        except (json.JSONDecodeError, Exception) as exc:
            print(f"sendCommand error: {exc}")
            raise
        return payload
    async def sendCommand(
        self,
        experiment_id: str,
        command_big_hex: str,
        execute_time: Union[int, datetime],
        cmd_window_id: int,
    ) -> int:
        """
        Transmit a command to be executed at the specified time.

        Parameters
        ----------
        experiment_id   : str
        command_big_hex : str   – hex-encoded command payload
        execute_time    : int or datetime – when to execute (UTC)
        cmd_window_id   : int

        Returns
        -------
        int
            Server-assigned command ID on success.

        Raises
        ------
        RuntimeError if the server returns an error string instead of an int.
        """
        t_exec = self._to_unix(execute_time)

        try:
            payload = await self._send_command(
                "sendCommand",
                experiment_id,
                command_big_hex,
                t_exec,
                cmd_window_id,
            )
        except (json.JSONDecodeError, Exception) as exc:
            print(f"sendCommand error: {exc}")
            raise

        # Server returns an integer on success, an error string otherwise.
        if isinstance(payload, int):
            return payload
        print(f"sendCommand returned an error: {payload}")
        return None

    async def getcmdqueue(
        self,
        experiment_id: str,
        start: Union[int, datetime],
        end: Union[int, datetime],
        windowid: int,
        cmd_interpreter: CommandInterpreter = None
    ) -> list[QueuedCommand]:
        """
        Retrieve the command queue for an experiment within a time window.

        Parameters
        ----------
        experiment_id : str
        start         : int or datetime
        end           : int or datetime
        windowid      : int

        Returns
        -------
        list[QueuedCommand]
        """
        t_start = self._to_unix(start)
        t_end = self._to_unix(end)

        try:
            payload = await self._send_command(
                "getcmdqueue", experiment_id, t_start, t_end, windowid
            )
        except (json.JSONDecodeError, Exception) as exc:
            print(f"getcmdqueue error: {exc}")
            raise

        queue: list[QueuedCommand] = []
        for item in payload.get("commandqueue", []):
            # Key names in the spec have a trailing space ("command_id ") —
            # handle both the clean and the space-padded variants defensively.
            cmd_id = item.get("command_id") or item.get("command_id ")
            exp_id = item.get("experiment_id") or item.get("experiment_id ")
            
            if cmd_interpreter is not None:
                cmd = cmd_interpreter.process(item["command"])
            else:
                cmd = item["command"]
            queue.append(
                QueuedCommand(
                    command_id=int(cmd_id),
                    timestamp=self._from_unix(item["unixtimestamp"]),
                    experiment_id=str(exp_id),
                    command=cmd,
                    windowid=item["windowid"],
                    sent=item["sent"],
                )
            )
        return queue

async def main():
    global HunityAPI_Password, HunityAPI_User
    if HunityAPI_Password is None:
        HunityAPI_Password = input('Enter API password: ')
        
    async with HunityAPI() as api:
        logged_in = await api.login(HunityAPI_User, HunityAPI_Password)
        if not logged_in:
            return
        
        data = await api.getEXPData("spasic", 
                         dt.datetime.now(dt.timezone.utc) - timedelta(hours=12),
                         dt.datetime.now(dt.timezone.utc))
        print(data)
    

if __name__ == '__main__':
    print("Hello")
    asyncio.run(main())

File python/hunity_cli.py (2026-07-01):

#!/usr/bin/env python3
"""
hunity_cli.py

Interactive command-line interface to the WebSocket experiment API.
Imports and uses hunity_api.HunityAPI.
(C) 2026 Pat Deegan, https://psychogenic.com 


Supported CLI commands
----------------------
  set <VAR> <VALUE>          – set a variable (exp_id, user, password, port)
  get [VAR]                  – show one or all variable values
  model <GROUND|FLIGHT>      – set the model you connect to
  connect                    – open WebSocket and login
  disconnect                 – close WebSocket connection
  
  command_windows [NUMDAYS]  – list command windows from now to now+NUMDAYS
  
  command_queue  <WINDOWID> [NUMDAYS] [START]
                             – list commands for window
  send_commands <WINDOW_ID> <CSVFILE>
                             – read CSV and send each row as a command
  send_command_single <WINDOW_ID> <DEADLINE> <HEX_COMMAND>
                             – send the single command
  delete_command <CMDID>     – delete a previously queued command
  
  experiment_data <START> [DELTASECONDS]
                             – get experimental data (START 0 == "now", relative int is seconds from now,
                               giant int is unix timestamp)
  
  help                       – show this help
  
  
  exit / quit                – leave the CLI
"""
import atexit
import asyncio
import csv
import os
import readline
import struct
import sys
from datetime import datetime, timedelta, timezone
import datetime as dt
from typing import Optional, Union

from hunity_api import HunityAPI, PortGroundModel, PortFlightModel, HunityAPI_ExpName, HunityAPI_User, HunityAPI_Password
from hunity_api import ExperimentData, CommandInterpreter
OutputRawResponses = False
# ---------------------------------------------------------------------------
# Tab-completion
# ---------------------------------------------------------------------------

COMMANDS = [
    "set", "get", "connect", "disconnect", "model",
    "command_windows", "command_queue", "send_commands", 
    "command_delete",
    "send_command_single",
    "delete_command",
    "experiment_data",
    "poll", "help", "exit", "quit",
]
VARIABLES = ["exp_id", "user", "password", "port"]


def _completer(text: str, state: int) -> Optional[str]:
    buf = readline.get_line_buffer().lstrip()
    tokens = buf.split()

    # First token: complete command names
    if len(tokens) == 0 or (len(tokens) == 1 and not buf.endswith(" ")):
        options = [c for c in COMMANDS if c.startswith(text)]
    # Second token after "set" or "get": complete variable names
    elif len(tokens) >= 1:
        if tokens[0] in ("set", "get"):
            options = [v for v in VARIABLES if v.startswith(text)]
        elif tokens[0] == "model":
            options = [v for v in ["GROUND", "FLIGHT"] if v.startswith(text.upper())]
        else:
            options = []
    else:
        options = []

    return options[state] if state < len(options) else None


readline.set_completer(_completer)
readline.parse_and_bind("tab: complete")
history_file = os.path.expanduser("~/.hunity_cli")
readline.set_history_length(1000)
atexit.register(readline.write_history_file, history_file)

if os.path.exists(history_file):
    try:
        readline.read_history_file(history_file)
    except OSError:
        pass  # Handle empty or corrupted history files smoothly




# ---------------------------------------------------------------------------
# Hex conversion helper
# ---------------------------------------------------------------------------

def _little_endian_hex_to_big_endian_upper(hex_str: str) -> str:
    """
    Convert a little-endian hex string (with or without 0x prefix) to
    upper-case big-endian hex without prefix.

    Example: "0x0000000000000053"  ->  "5300000000000000"
             "0x000000474e500150"  ->  "5001504e47000000"
    """
    hex_str = hex_str.strip()
    if hex_str.lower().startswith("0x"):
        hex_str = hex_str[2:]

    if len(hex_str) % 2 != 0:
        hex_str = "0" + hex_str  # pad to even length

    # Interpret as a sequence of bytes, then reverse for big-endian
    byte_seq = bytes.fromhex(hex_str)
    return byte_seq[::-1].hex().upper()


# ---------------------------------------------------------------------------
# CLI state
# ---------------------------------------------------------------------------

class CLIState:
    def __init__(self, expdata_wrapper_class:ExperimentData = None, cmd_interpreter:CommandInterpreter = None) -> None:
        self.vars: dict[str, str] = {
            "exp_id":   "" if HunityAPI_ExpName is None else HunityAPI_ExpName,  
            "user":     "" if HunityAPI_User is None else HunityAPI_User, 
            "password": "" if HunityAPI_Password is None else HunityAPI_Password, 
            "port":     str(PortGroundModel),
        }
        self.client: Optional[HunityAPI] = None
        self.connected: bool = False
        self.expdata_wrapper: ExperimentData = expdata_wrapper_class 
        self.cmd_interpreter: CommandInterpreter = cmd_interpreter
        self._command_windows = {}
        
    @property
    def model(self) -> str:
        if self.vars["port"] == str(PortGroundModel):
            return "ground"
        if self.vars["port"] == str(PortFlightModel):
            return "flight"
        return "n/a"
    @property
    def prompt(self) -> str:
        exp = self.vars["exp_id"]
        if self.connected and exp:
            return f"{exp} ({self.model})> "
        return "> "

    def _require_connected(self) -> bool:
        if not self.connected or self.client is None:
            print("Not connected. Run 'connect' first.")
            return False
        return True
        
    def _to_unix(self, ts: Union[int, datetime, None]) -> Optional[int]:
        """Convert datetime to Unix timestamp (int32 style) or pass through int/None."""
        if ts is None:
            return None
        if isinstance(ts, datetime):
            return int(ts.timestamp())  # Unix timestamp (UTC)
        if isinstance(ts, (int, float)):
            return int(ts)
        raise TypeError(f"Expected int, datetime or None, got {type(ts)}")
    
    def _from_unix(self, ts: Union[int, float, None]) -> Optional[datetime]:
        """Convert Unix timestamp to datetime (UTC)."""
        if ts is None:
            return None
        return datetime.fromtimestamp(ts, tz=dt.timezone.utc)
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

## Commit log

2025-03-29 assumption req for i2c bus malfunction heartbeat/timeout
2025-04-13 TT Experiment board hardware
    [5050660622.step, 5050700622.stp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]
2025-04-15 reduced-height flash (dual footprint), layout rework, markings
    [TTExperimentModule-B_Cu.gbr, TTExperimentModule-B_Mask.gbr, TTExperimentModule-B_Paste.gbr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]
2025-04-21 BOM updates for spaaaaaace
    [TTExperimentModule.kicad_sch, rp2040.kicad_sch, tt_asic.kicad_sch]
2025-04-21 basic 2-core spasic framework
2025-04-29 attempt to run without thread, still smashing stack
2025-04-29 Multiple experiment framework, running
2025-04-29 Experiment list and failing exp
    [loader.py]
2025-04-29 TT06 DB firmware with i2cslave and latest spasic driver
2025-04-29 Watchdog enabled, no print() in isr cb (!), and quicker queueing of exp run response
2025-04-29 stress test includes reboots and forever loops/abort
    [i2c_client_test.py]
2025-04-30 error message parsing bug fix
    [i2c_client_test.py]
2025-05-01 test experiment fixes and improvements
    [loader.py]
2025-05-01 i2c simulation device for dev
2025-05-01 i2c and general debug assists
2025-05-01 File upload and client rework
    [i2c_client_packets.py, i2c_client_test.py, i2c_server.py]
2025-05-06 reboots without watchdog aren't great
    [watchdog.py]
2025-05-06 Pure polling i2c slave device (working!?), 0x00 empty bytes
2025-05-09 experiment immediate result and error code interp.
    [i2c_client_packets.py, i2c_client_test.py]
2025-05-09 clear arg swap or aborts
    [i2c_server.py]
2025-05-09 info responses, time sync track, clean-up and settings for production/delivery
2025-05-09 updated sample packetdumper interaction
2025-05-27 prettification, finer ctrl and util func for i2c client test
2025-05-27 version bump and i2c p-u off for deployment
2025-06-15 Made rp2 temp exp interruptable
2025-07-01 Experiment module request scheduling
    [ExperimentRequests.ods]
2025-11-26 mods to exp run spreadsheet and docs
    [ExperimentRequests.ods]
2026-01-06 module commands requested log
    [ExperimentRequests-001_preliminary.csv, ExperimentRequests-001_preliminary.ods, ExperimentRequests-002.csv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]
2026-01-10 commands request 003
    [spasic-exp-request003.csv]
2026-01-10 First responses from LEO!
    [spasic_002_parsed.csv, spasic_002_telemetry_20260108.csv]
2026-01-14 sat request 003 responses received
    [exptelemetry_spasic_20260111_20260112-parsed.csv, exptelemetry_spasic_20260111_20260112.csv]
2026-01-14 re-parse with tt_um_qubitbytes_alive result interpreter
    [exptelemetry_spasic_20260111_20260112-parsed.csv]
2026-03-25 experiment run 004 request and responses
    [ExperimentRequests-004.csv, ExperimentRequests-004.ods, spasic_004_parsed.csv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]

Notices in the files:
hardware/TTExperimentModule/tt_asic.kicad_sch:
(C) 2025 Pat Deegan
